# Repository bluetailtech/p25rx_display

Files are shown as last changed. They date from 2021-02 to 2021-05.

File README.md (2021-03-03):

# p25rx_display
Touch-lcd display for use with the P25RX receiver

Build Instructions (tested on a Debian system)

1) download GNU ARM Embedded Toolchain from here:
2) https://developer.arm.com/tools-and-software/open-source-software/developer-tools/gnu-toolchain/gnu-rm/downloads
3) The current firmare was compiled with version: 7-2018q2-update
4) Create a symbolic link to the compiler in the project directory:  'ln -s gcc-arm-none-eabi-7-2018-q2-update arm-toolchain'
5) Now you can compile the project from the project directory with:  'make'
6) Flip SW2 to the ON position before supplying power to the pcb. This will put the MCU into DFU programming mode.
7) Download the dfu-util software: http://dfu-util.sourceforge.net/
8) Program the device with dfu-util:   'dfu-util --device 0483:df11 -a 0 -s 0x08000000 -D build/p25rx_display_DFU.bin'
9) Return SW2 to the OFF position and cycle power.

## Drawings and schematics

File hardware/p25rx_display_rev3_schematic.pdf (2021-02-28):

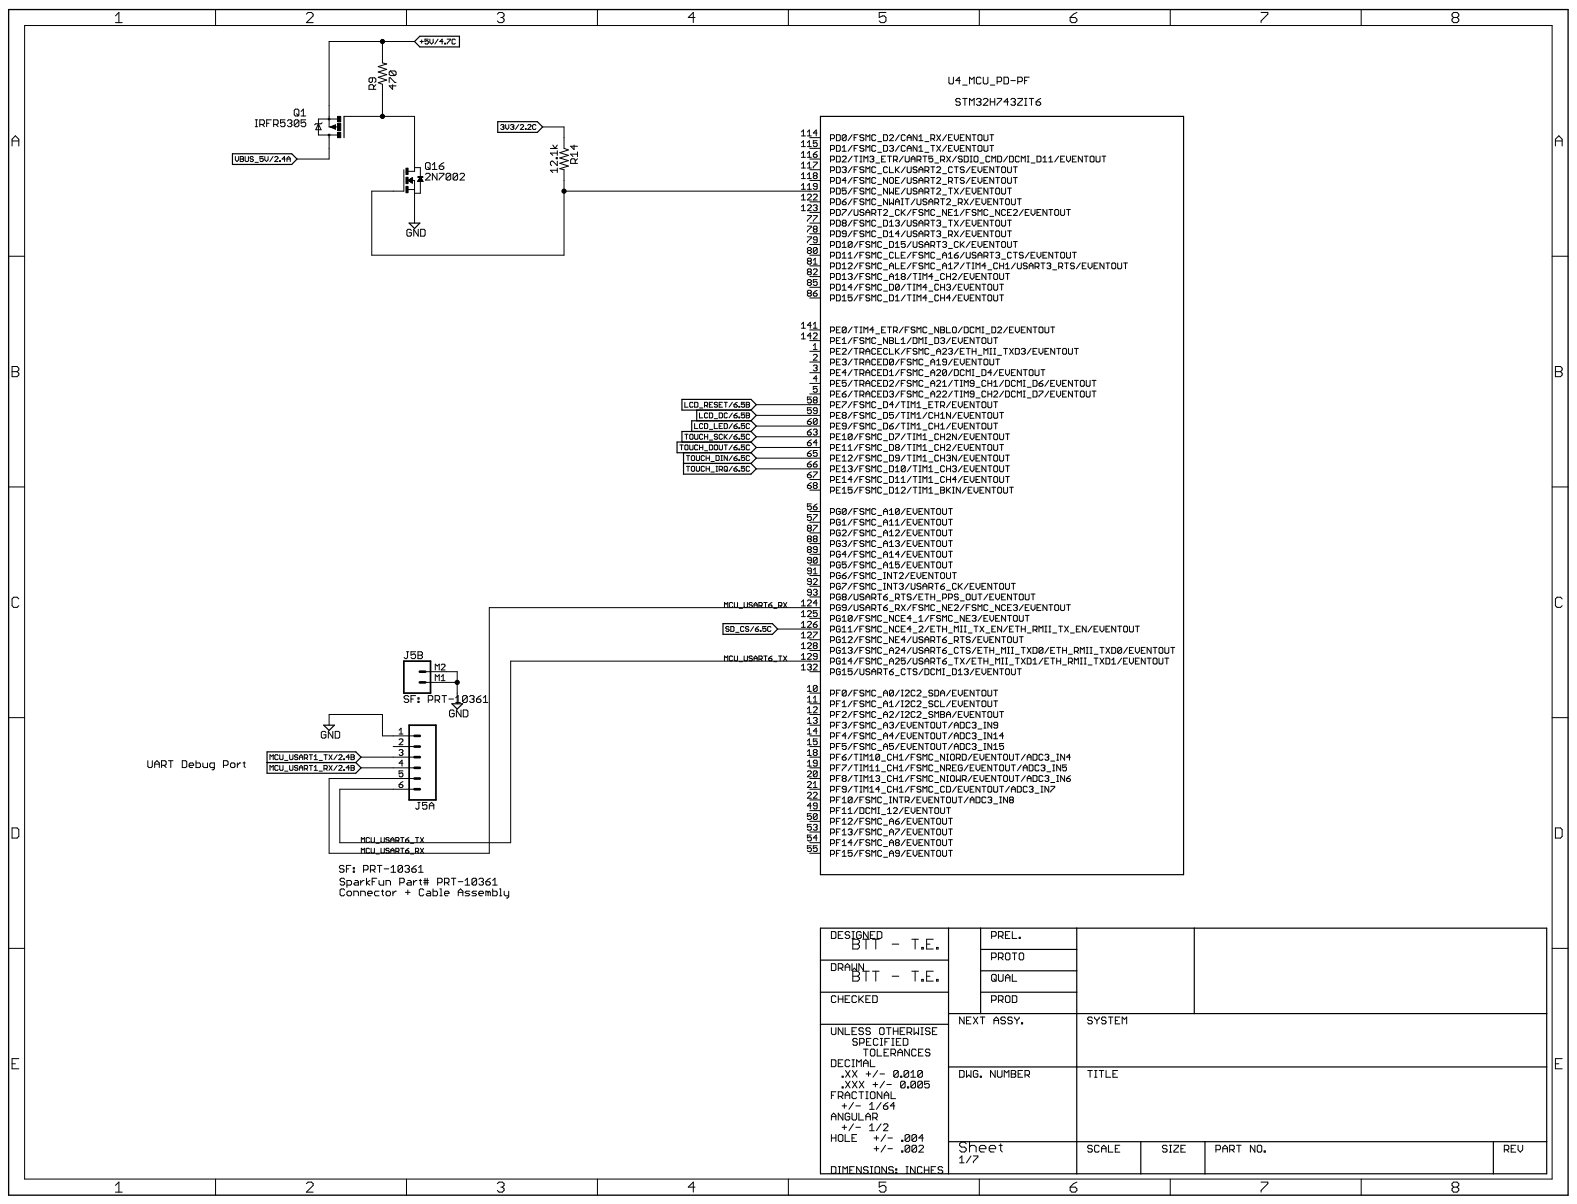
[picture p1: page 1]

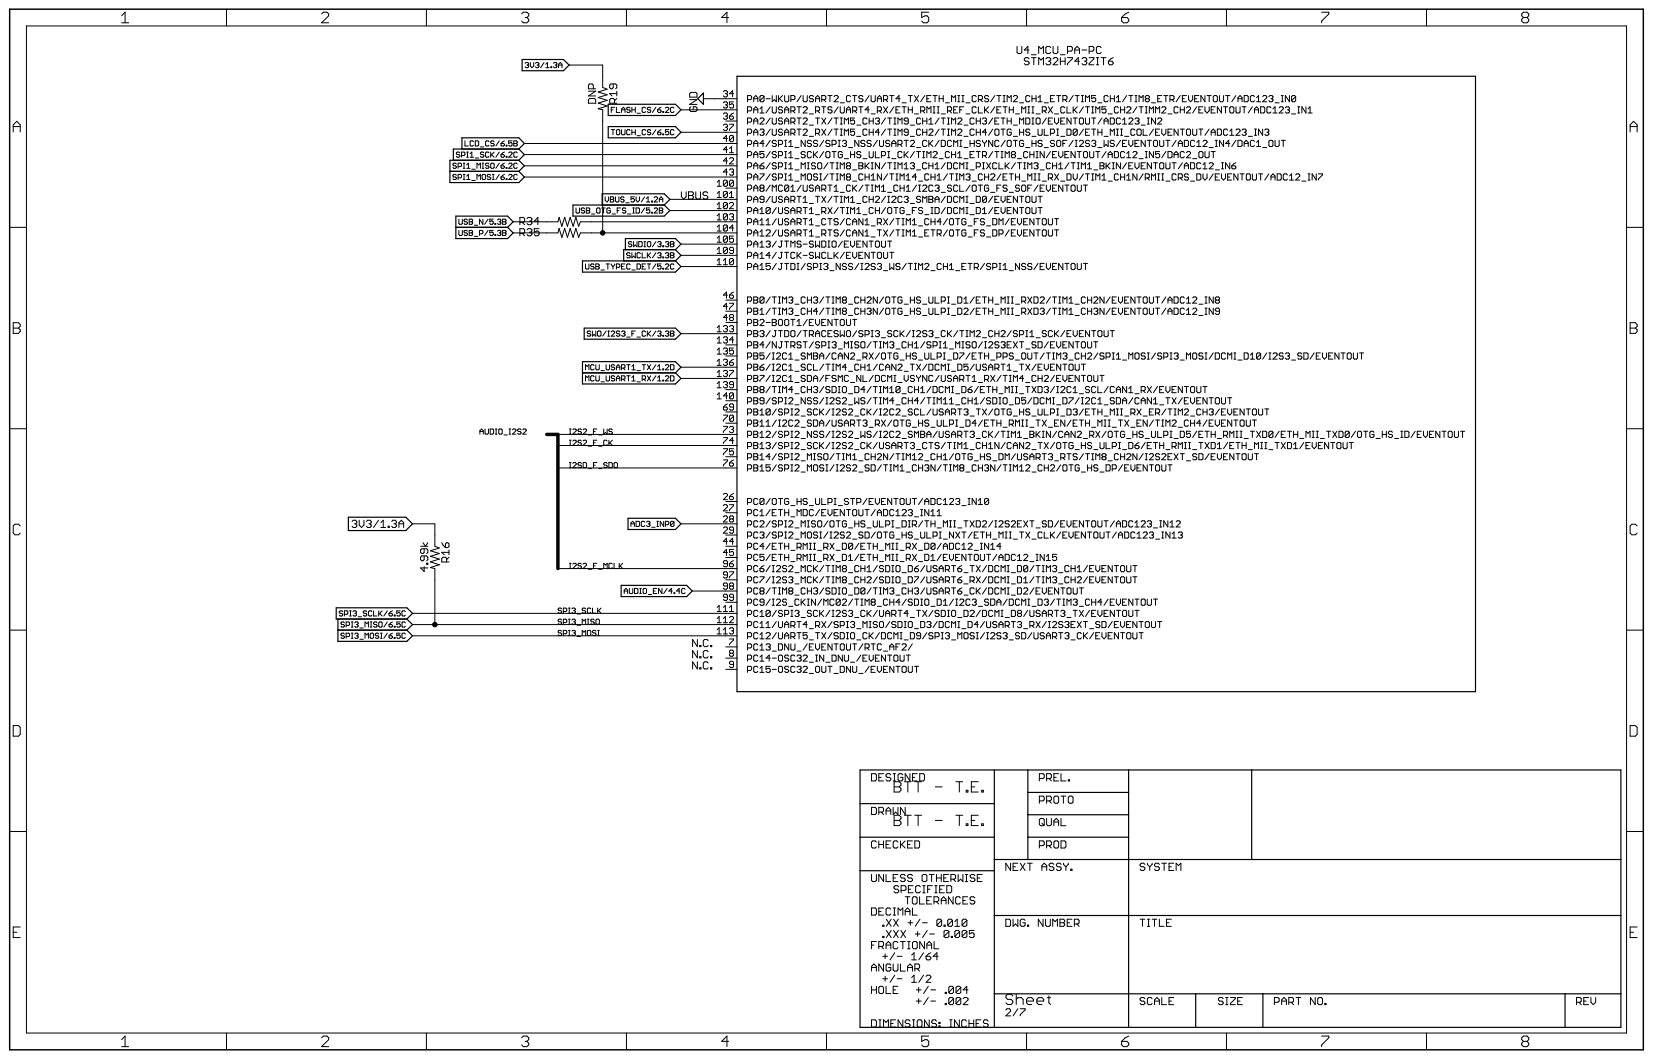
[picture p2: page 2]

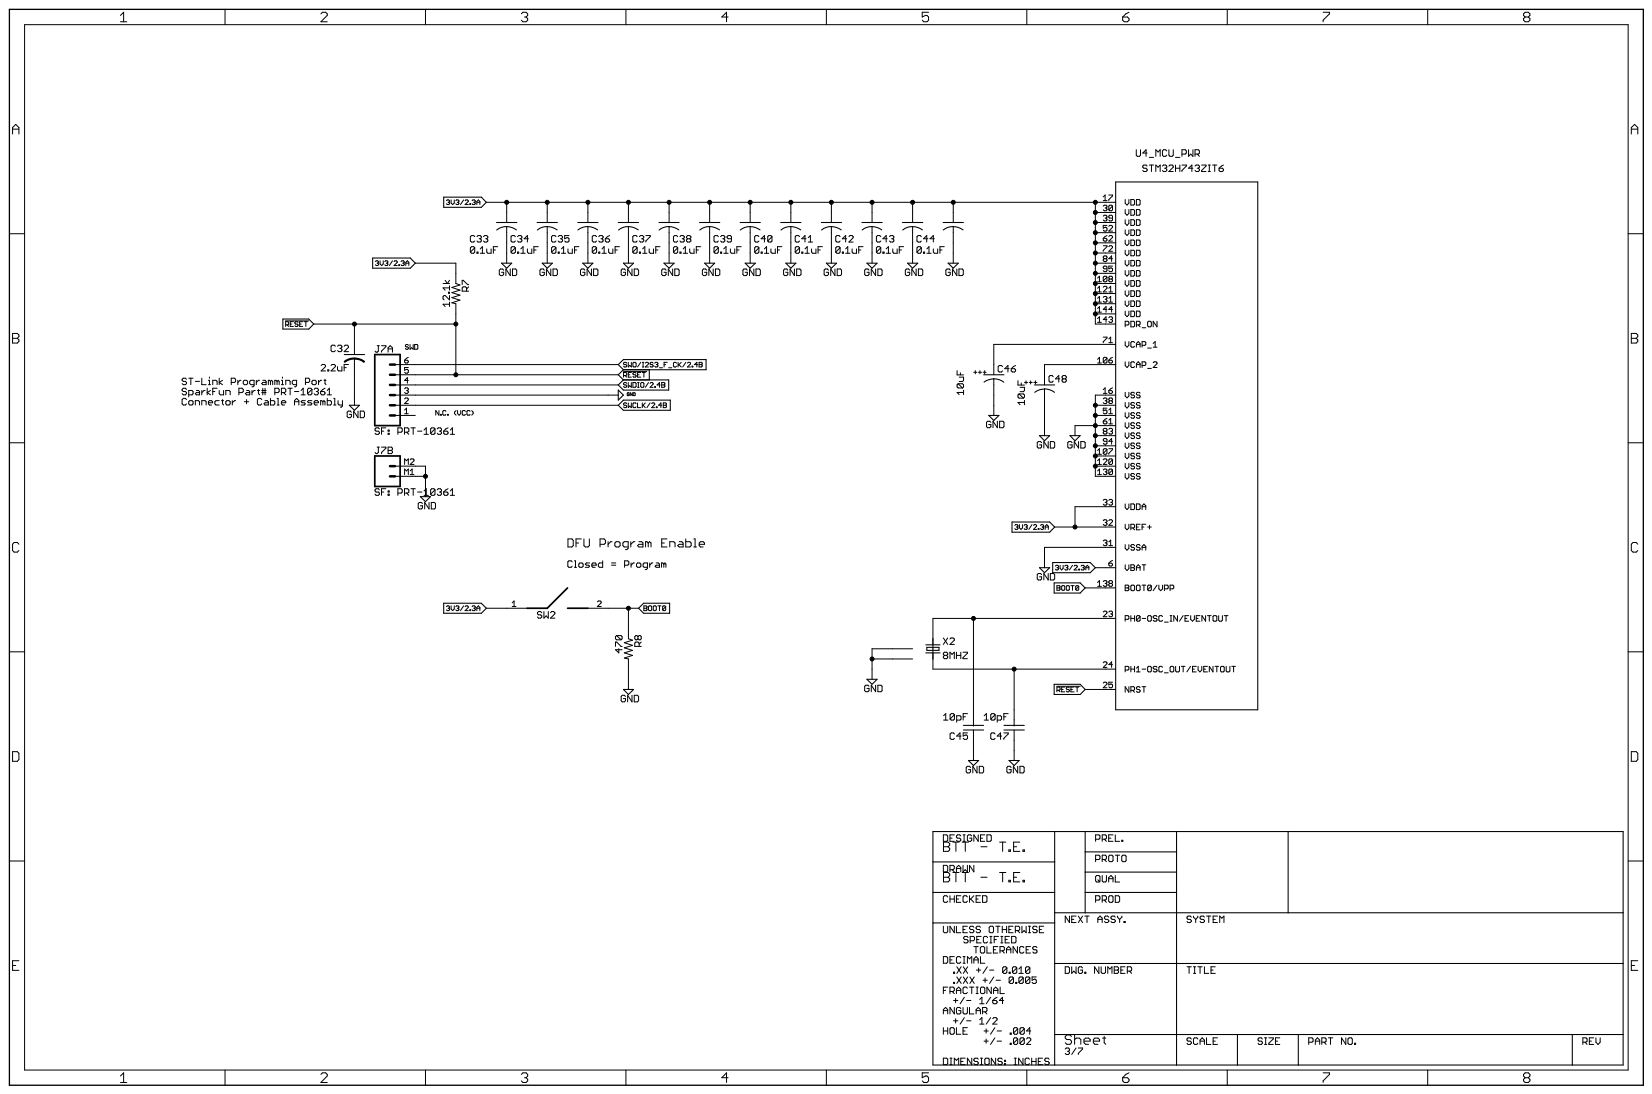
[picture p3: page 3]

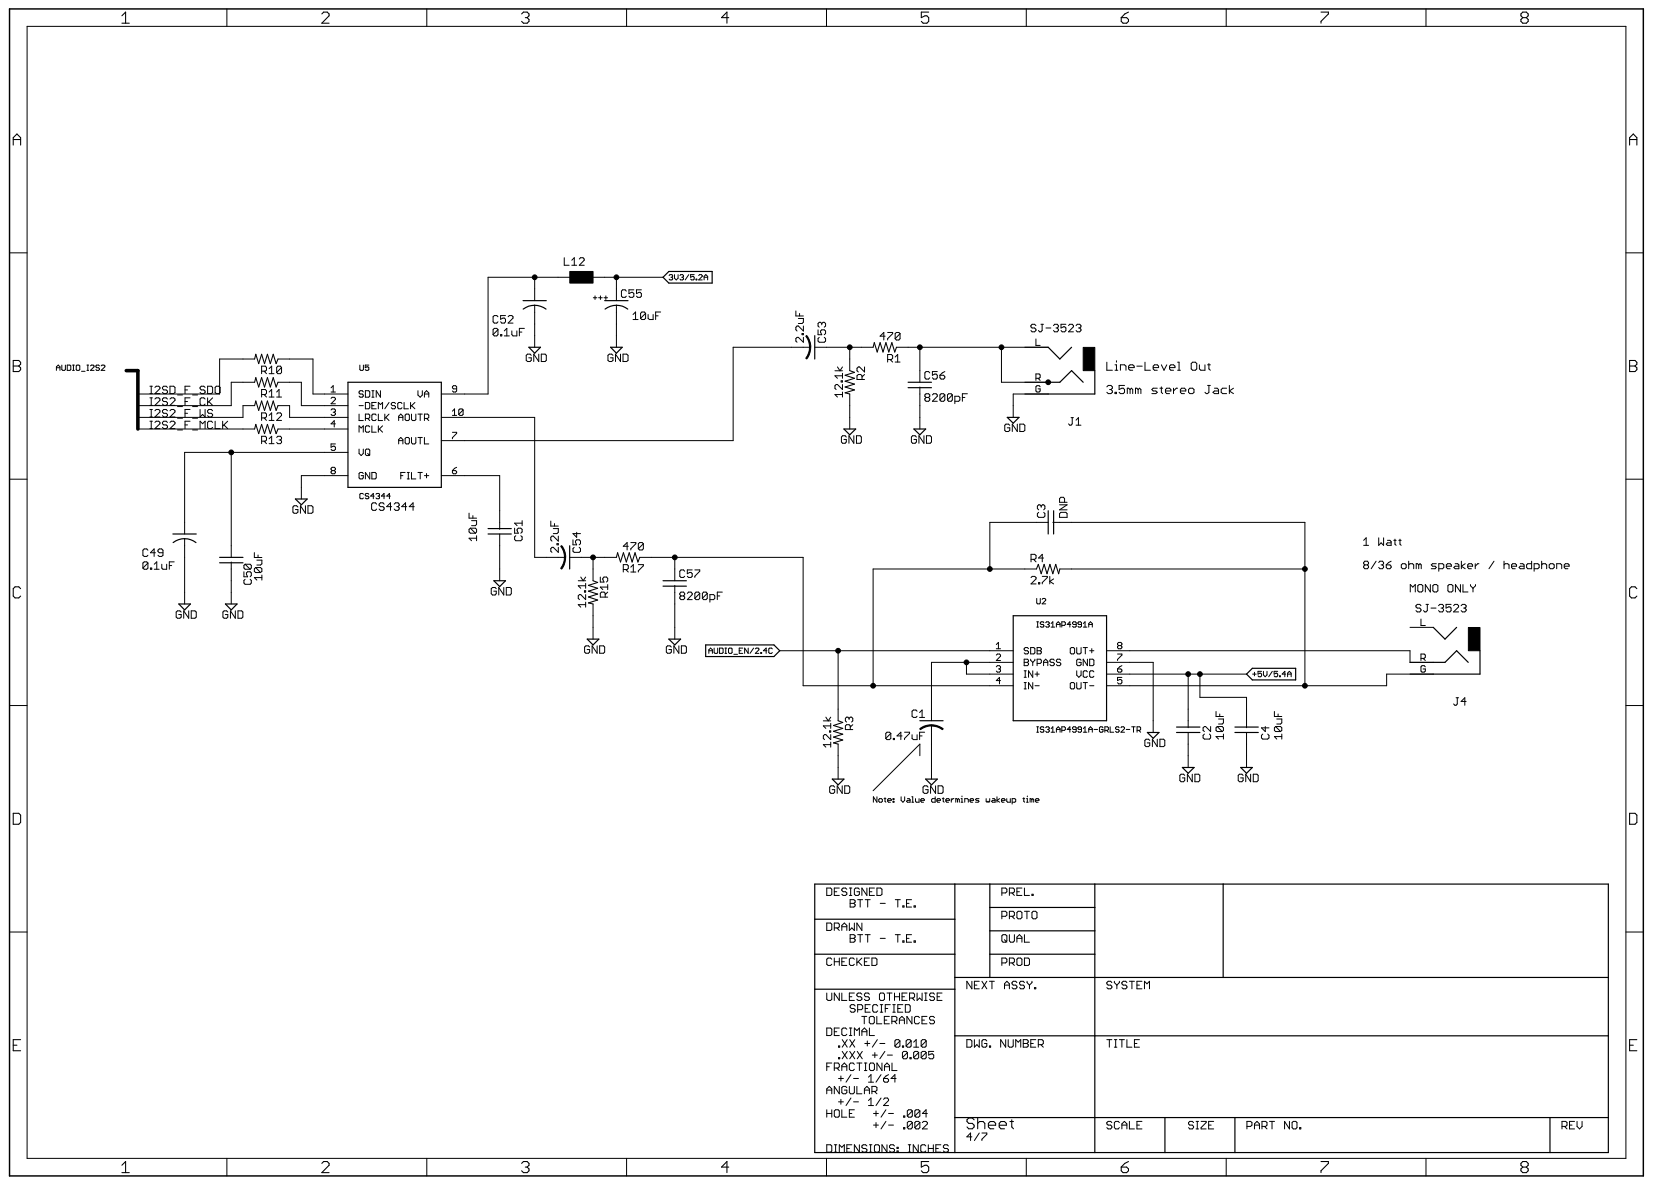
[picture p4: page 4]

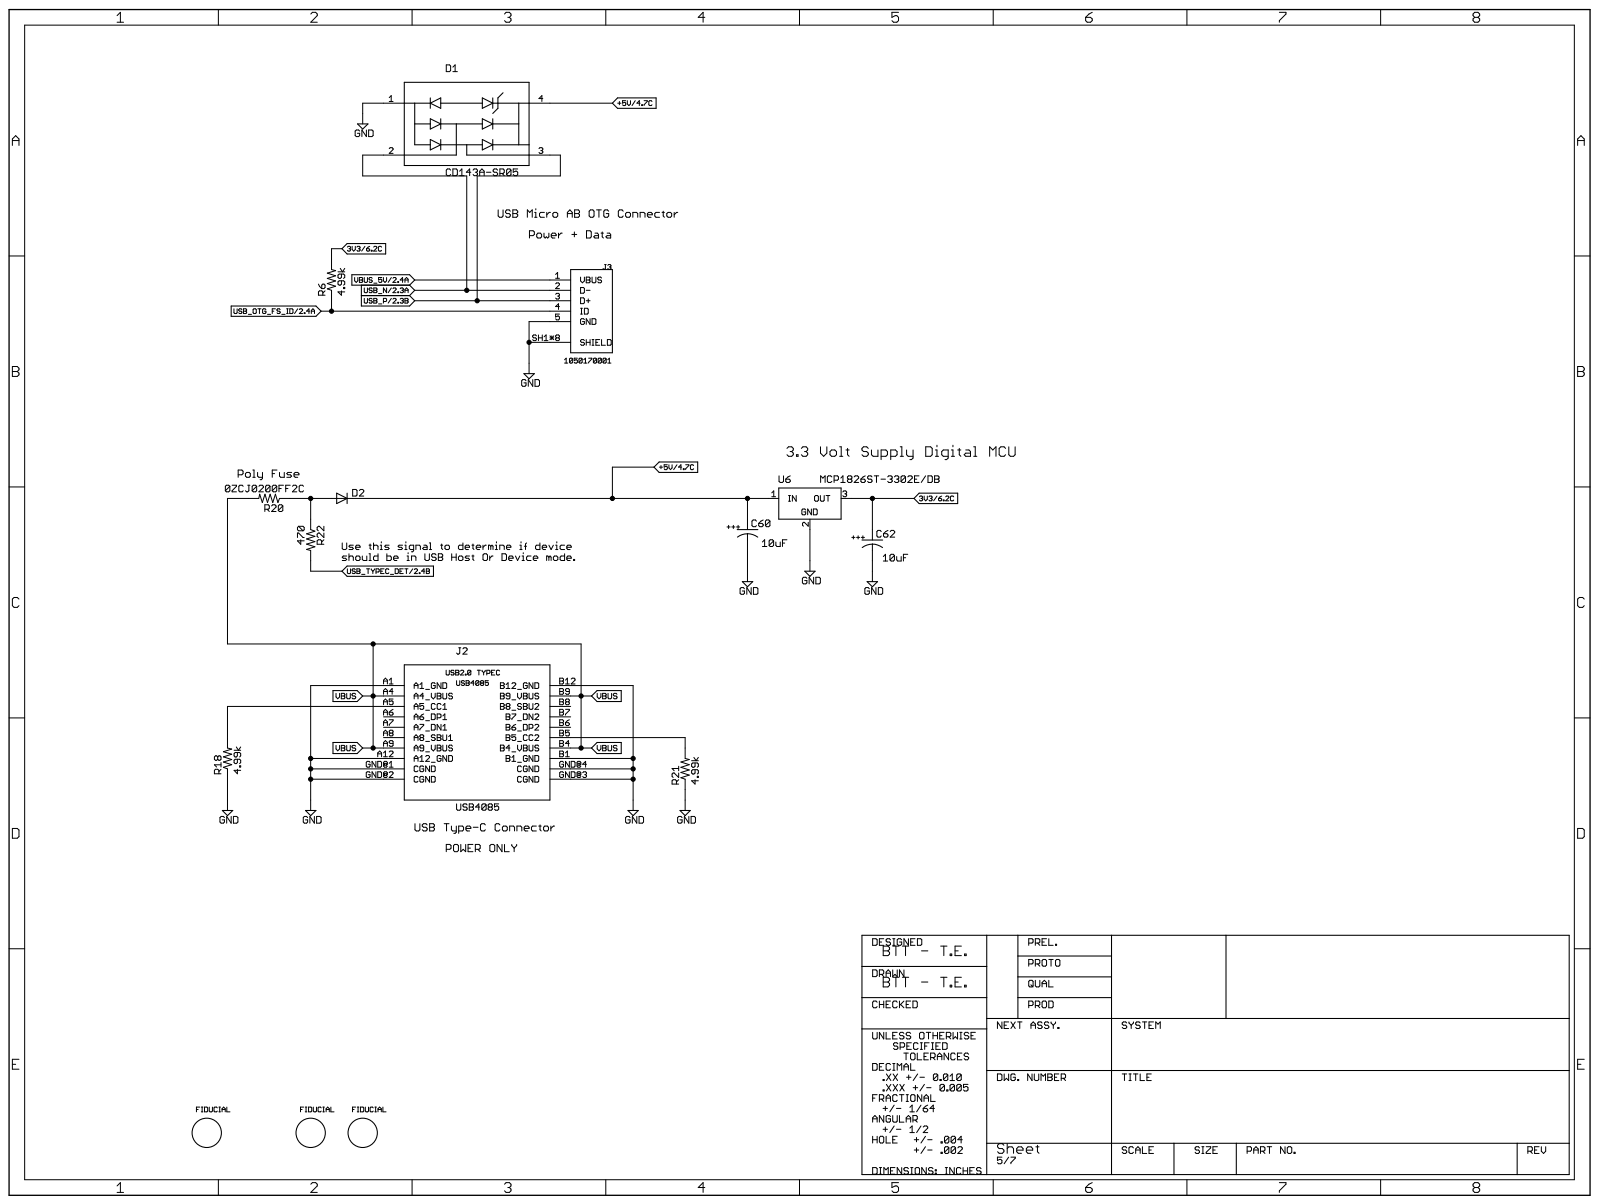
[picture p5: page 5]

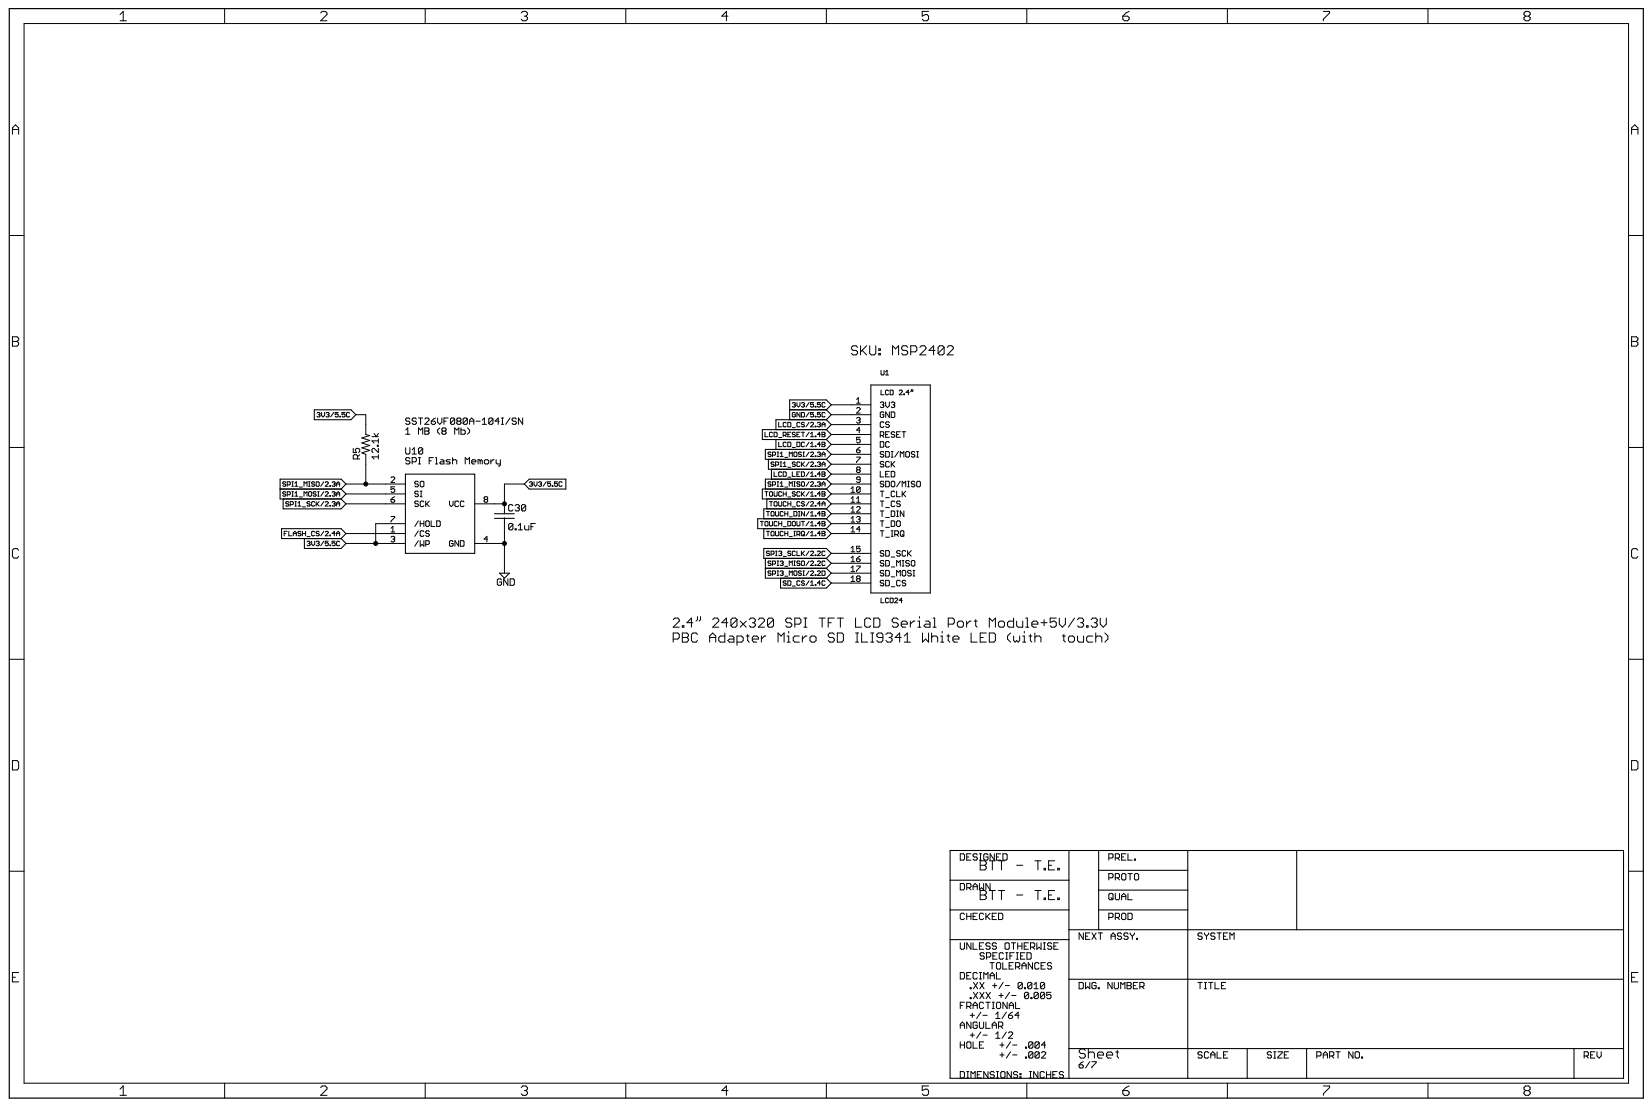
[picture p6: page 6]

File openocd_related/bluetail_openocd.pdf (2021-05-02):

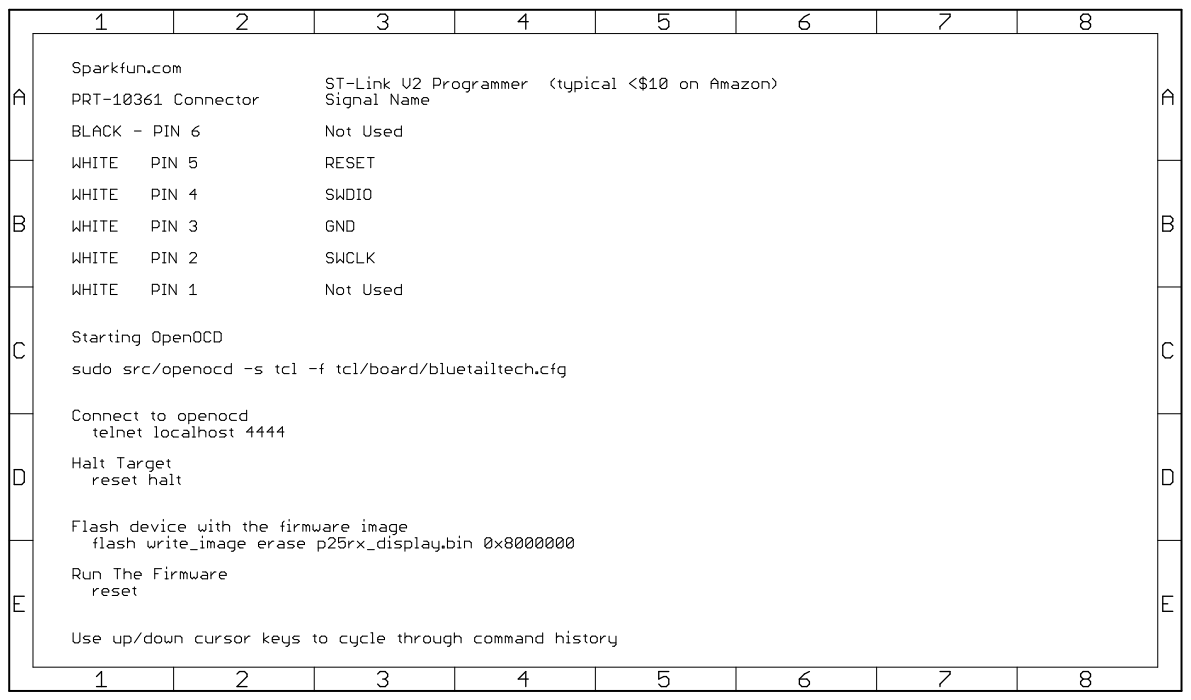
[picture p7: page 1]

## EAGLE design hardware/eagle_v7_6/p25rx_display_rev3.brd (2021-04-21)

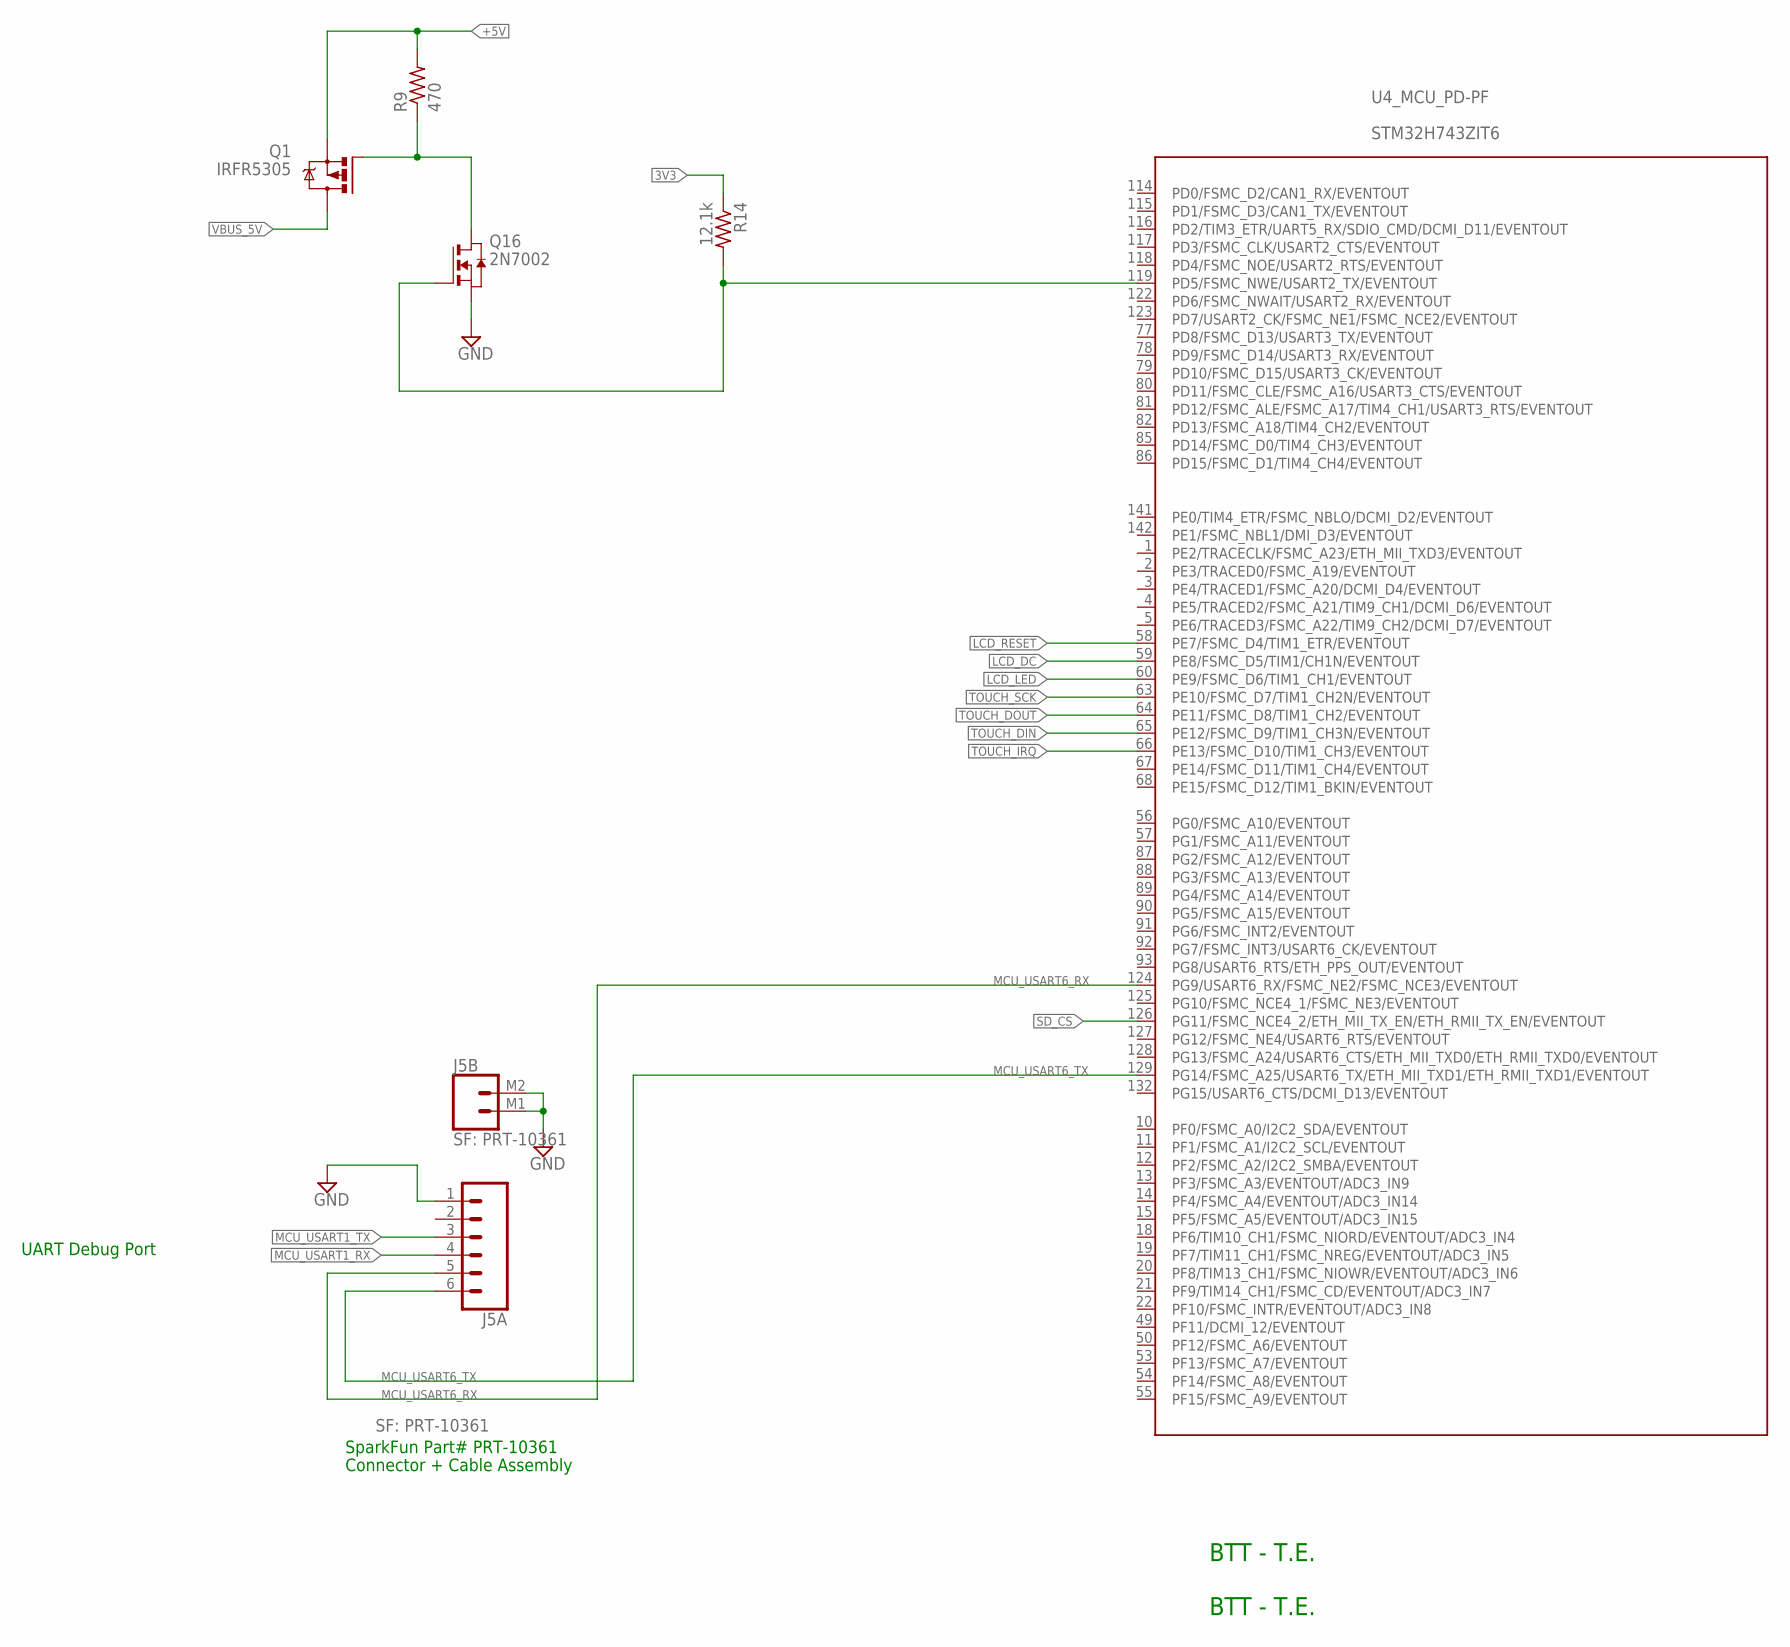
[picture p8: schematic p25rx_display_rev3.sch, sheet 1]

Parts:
J5: SF: PRT-10361; JST-6-SMD-HORI-1.0MM
Q1: IRFR5305; D-PAK_TO252AA
Q16: 2N7002; SOT23_2N7002_PACKAGE
R9: 470; R0603
R14: 12.1k; R0402
U4: STM32H743ZIT6; STM32F407_144

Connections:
3V3: R14.1; also elsewhere on the board
+5V: Q1.3 (S), R9.2; also elsewhere on the board
GND: J5.1, J5.M1 (1), J5.M2 (2), Q16.2 (S); also elsewhere on the board
LCD_DC: U4.59 (PE8/FSMC_D5/TIM1/CH1N/EVENTOUT); also elsewhere on the board
LCD_LED: U4.60 (PE9/FSMC_D6/TIM1_CH1/EVENTOUT); also elsewhere on the board
LCD_RESET: U4.58 (PE7/FSMC_D4/TIM1_ETR/EVENTOUT); also elsewhere on the board
MCU_USART1_RX: J5.4; also elsewhere on the board
MCU_USART1_TX: J5.3; also elsewhere on the board
MCU_USART6_RX: J5.5, U4.124 (PG9/USART6_RX/FSMC_NE2/FSMC_NCE3/EVENTO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)
MCU_USART6_TX: J5.6, U4.129 (PG14/FSMC_A25/USART6_TX/ETH_MII_TXD1/ET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)
unnamed: Q16.1 (G), R14.2, U4.119 (PD5/FSMC_NWE/USART2_TX/EVENTOUT)
unnamed: Q1.1 (G), Q16.3 (D), R9.1
SD_CS: U4.126 (PG11/FSMC_NCE4_2/ETH_MII_TX_EN/ETH_RMII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); also elsewhere on the board
TOUCH_DIN: U4.65 (PE12/FSMC_D9/TIM1_CH3N/EVENTOUT); also elsewhere on the board
TOUCH_DOUT: U4.64 (PE11/FSMC_D8/TIM1_CH2/EVENTOUT); also elsewhere on the board
TOUCH_IRQ: U4.66 (PE13/FSMC_D10/TIM1_CH3/EVENTOUT); also elsewhere on the board
TOUCH_SCK: U4.63 (PE10/FSMC_D7/TIM1_CH2N/EVENTOUT); also elsewhere on the board
VBUS_5V: Q1.4 (D); also elsewhere on the board

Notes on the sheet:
BTT - T.E.
UART Debug Port
SparkFun Part# PRT-10361
Connector + Cable Assembly

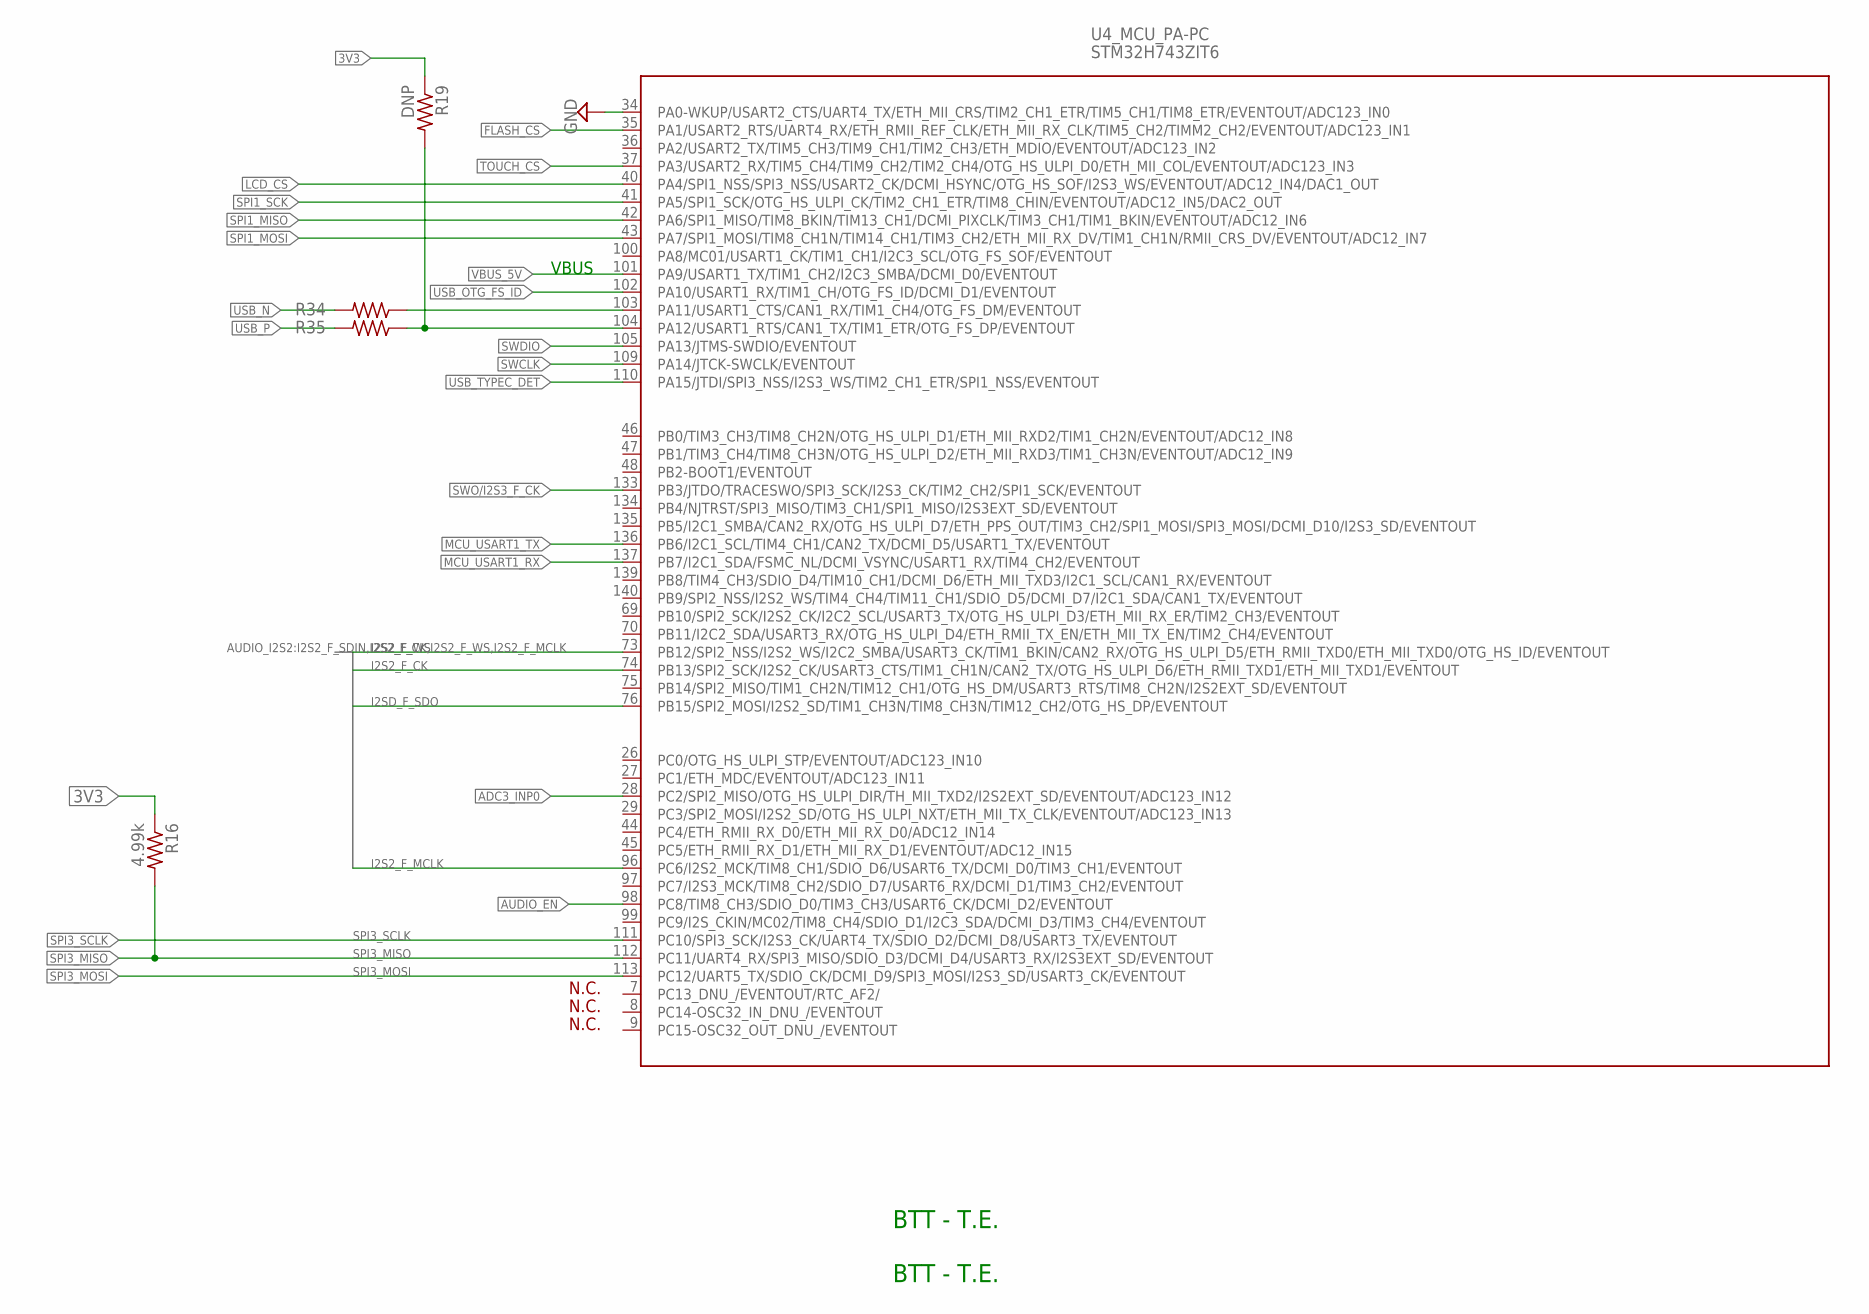
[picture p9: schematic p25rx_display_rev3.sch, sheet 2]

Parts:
R16: 4.99k; R0402
R19: DNP; R0603
R34, R35: 470; R0402
U4: STM32H743ZIT6; STM32F407_144

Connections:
3V3: R16.1, R19.1; also elsewhere on the board
ADC3_INP0: U4.28 (PC2/SPI2_MISO/OTG_HS_ULPI_DIR/TH_MII_TX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)
AUDIO_EN: U4.98 (PC8/TIM8_CH3/SDIO_D0/TIM3_CH3/USART6_CK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); also elsewhere on the board
FLASH_CS: U4.35 (PA1/USART2_RTS/UART4_RX/ETH_RMII_REF_CL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); also elsewhere on the board
GND: U4.34 (PA0-WKUP/USART2_CTS/UART4_TX/ETH_MII_CR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); also elsewhere on the board
I2S2_F_CK: U4.74 (PB13/SPI2_SCK/I2S2_CK/USART3_CTS/TIM1_C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); also elsewhere on the board
I2S2_F_MCLK: U4.96 (PC6/I2S2_MCK/TIM8_CH1/SDIO_D6/USART6_TX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); also elsewhere on the board
I2S2_F_WS: U4.73 (PB12/SPI2_NSS/I2S2_WS/I2C2_SMBA/USART3_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); also elsewhere on the board
I2SD_F_SDO: U4.76 (PB15/SPI2_MOSI/I2S2_SD/TIM1_CH3N/TIM8_C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); also elsewhere on the board
LCD_CS: U4.40 (PA4/SPI1_NSS/SPI3_NSS/USART2_CK/DCMI_HS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); also elsewhere on the board
MCU_USART1_RX: U4.137 (PB7/I2C1_SDA/FSMC_NL/DCMI_VSYNC/USART1_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); also elsewhere on the board
MCU_USART1_TX: U4.136 (PB6/I2C1_SCL/TIM4_CH1/CAN2_TX/DCMI_D5/U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); also elsewhere on the board
SPI1_MISO: U4.42 (PA6/SPI1_MISO/TIM8_BKIN/TIM13_CH1/DCMI_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); also elsewhere on the board
SPI1_MOSI: U4.43 (PA7/SPI1_MOSI/TIM8_CH1N/TIM14_CH1/TIM3_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); also elsewhere on the board
SPI1_SCK: U4.41 (PA5/SPI1_SCK/OTG_HS_ULPI_CK/TIM2_CH1_ET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); also elsewhere on the board
SPI3_MISO: R16.2, U4.112 (PC11/UART4_RX/SPI3_MISO/SDIO_D3/DCMI_D4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); also elsewhere on the board
SPI3_MOSI: U4.113 (PC12/UART5_TX/SDIO_CK/DCMI_D9/SPI3_MOSI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); also elsewhere on the board
SPI3_SCLK: U4.111 (PC10/SPI3_SCK/I2S3_CK/UART4_TX/SDIO_D2/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); also elsewhere on the board
SWCLK: U4.109 (PA14/JTCK-SWCLK/EVENTOUT); also elsewhere on the board
SWDIO: U4.105 (PA13/JTMS-SWDIO/EVENTOUT); also elsewhere on the board
SWO/I2S3_F_CK: U4.133 (PB3/JTDO/TRACESWO/SPI3_SCK/I2S3_CK/TIM2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); also elsewhere on the board
TOUCH_CS: U4.37 (PA3/USART2_RX/TIM5_CH4/TIM9_CH2/TIM2_CH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); also elsewhere on the board
USB_MCU_N: R34.1, U4.103 (PA11/USART1_CTS/CAN1_RX/TIM1_CH4/OTG_FS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)
USB_MCU_P: R19.2, R35.1, U4.104 (PA12/USART1_RTS/CAN1_TX/TIM1_ETR/OTG_FS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)
USB_N: R34.2; also elsewhere on the board
USB_OTG_FS_ID: U4.102 (PA10/USART1_RX/TIM1_CH/OTG_FS_ID/DCMI_D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); also elsewhere on the board
USB_P: R35.2; also elsewhere on the board
USB_TYPEC_DET: U4.110 (PA15/JTDI/SPI3_NSS/I2S3_WS/TIM2_CH1_ETR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); also elsewhere on the board
VBUS_5V: U4.101 (PA9/USART1_TX/TIM1_CH2/I2C3_SMBA/DCMI_D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); also elsewhere on the board

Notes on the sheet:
BTT - T.E.
VBUS

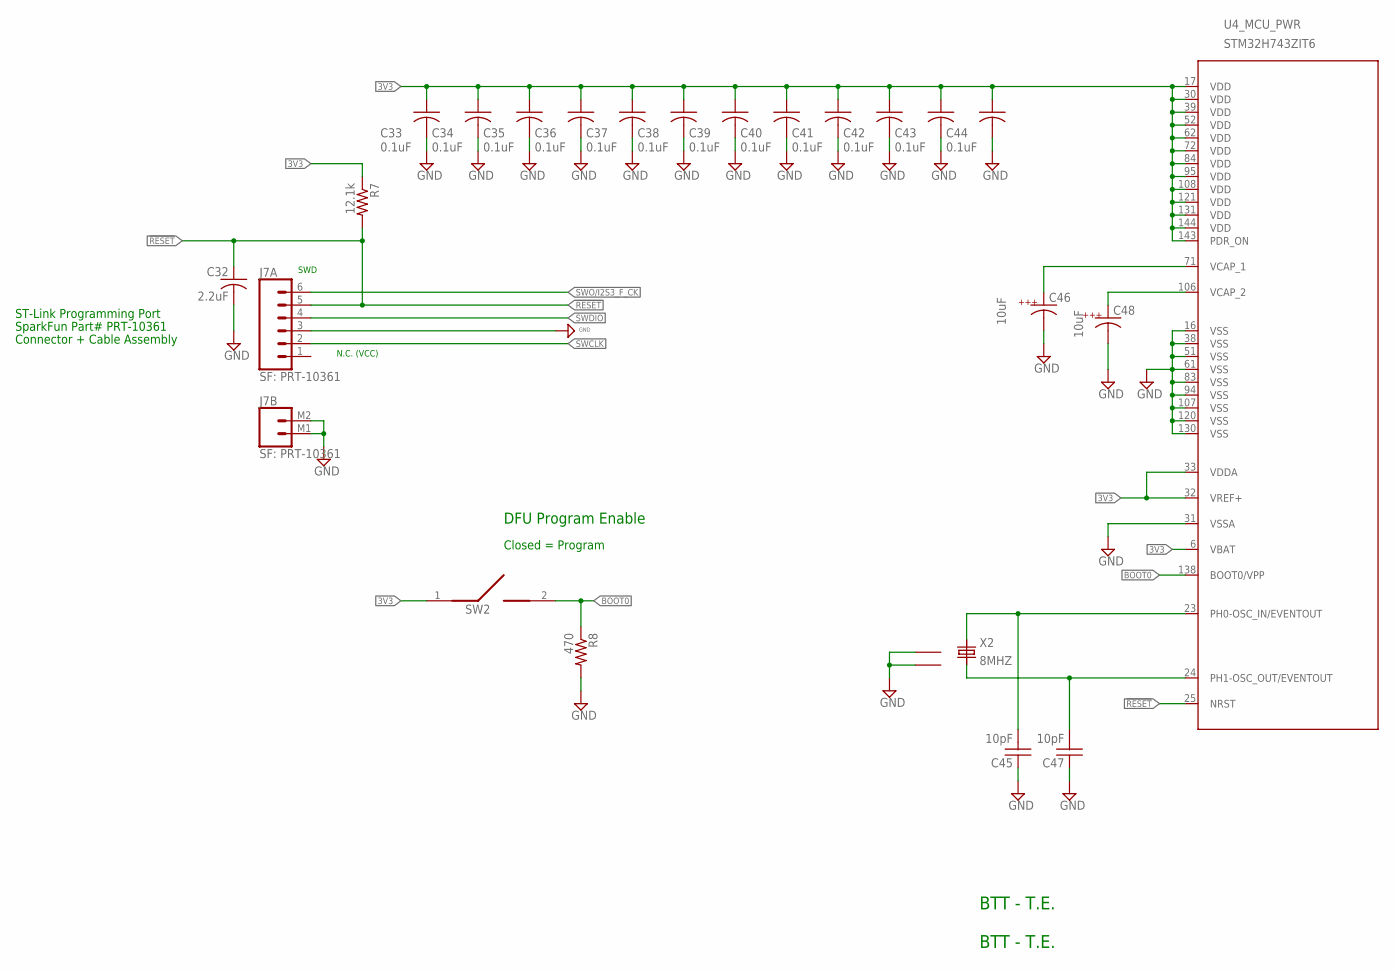
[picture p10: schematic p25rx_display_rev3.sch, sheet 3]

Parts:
C32: 2.2uF; C0805
C33, C34, C35, C36, C37, C38, C39, C40, C41, C42, C43, C44: 0.1uF; 0402
C45, C47: 10pF; C0603
C46, C48: 10uF; 1210K
J7: SF: PRT-10361; JST-6-SMD-HORI-1.0MM
R7: 12.1k; R0603
R8: 470; R0402
SW2: CHS-01TA; CHS1BIT
U4: STM32H743ZIT6; STM32F407_144
X2: 8MHZ; ECS-250-20-30B-DU_CRYSTAL

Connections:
3V3: C33.1 (A), C34.1 (A), C35.1 (A), C36.1 (A), C37.1 (A), C38.1 (A), C39.1 (A), C40.1 (A), C41.1 (A), C42.1 (A), C43.1 (A), C44.1 (A), R7.1, SW2.1, U4.6 (VBAT), U4.17 (VDD), U4.30 (VDD), U4.32 (VREF+), U4.33 (VDDA), U4.39 (VDD), U4.52 (VDD), U4.62 (VDD), U4.72 (VDD), U4.84 (VDD), U4.95 (VDD), U4.108 (VDD), U4.121 (VDD), U4.131 (VDD), U4.143 (PDR_ON), U4.144 (VDD); also elsewhere on the board
20MHZ_REF: C45.2, U4.23 (PH0-OSC_IN/EVENTOUT), X2.1
!RESET: C32.1, J7.5, R7.2, U4.25 (NRST)
BOOT0: R8.1, SW2.2, U4.138 (BOOT0/VPP)
GND: C32.2, C33.2 (C), C34.2 (C), C35.2 (C), C36.2 (C), C37.2 (C), C38.2 (C), C39.2 (C), C40.2 (C), C41.2 (C), C42.2 (C), C43.2 (C), C44.2 (C), C45.1, C46.C, C47.1, C48.C, J7.3, J7.M1 (1), J7.M2 (2), R8.2, U4.16 (VSS), U4.31 (VSSA), U4.38 (VSS), U4.51 (VSS), U4.61 (VSS), U4.83 (VSS), U4.94 (VSS), U4.107 (VSS), U4.120 (VSS), U4.130 (VSS), X2.GND@1 (1), X2.GND@2 (2); also elsewhere on the board
unnamed: C48.A, U4.106 (VCAP_2)
unnamed: C46.A, U4.71 (VCAP_1)
SWCLK: J7.2; also elsewhere on the board
SWDIO: J7.4; also elsewhere on the board
SWO/I2S3_F_CK: J7.6; also elsewhere on the board
X2: C47.2, U4.24 (PH1-OSC_OUT/EVENTOUT), X2.3

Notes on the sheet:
BTT - T.E.
SWD
N.C. (VCC)
DFU Program Enable
Closed = Program
ST-Link Programming Port
SparkFun Part# PRT-10361
Connector + Cable Assembly

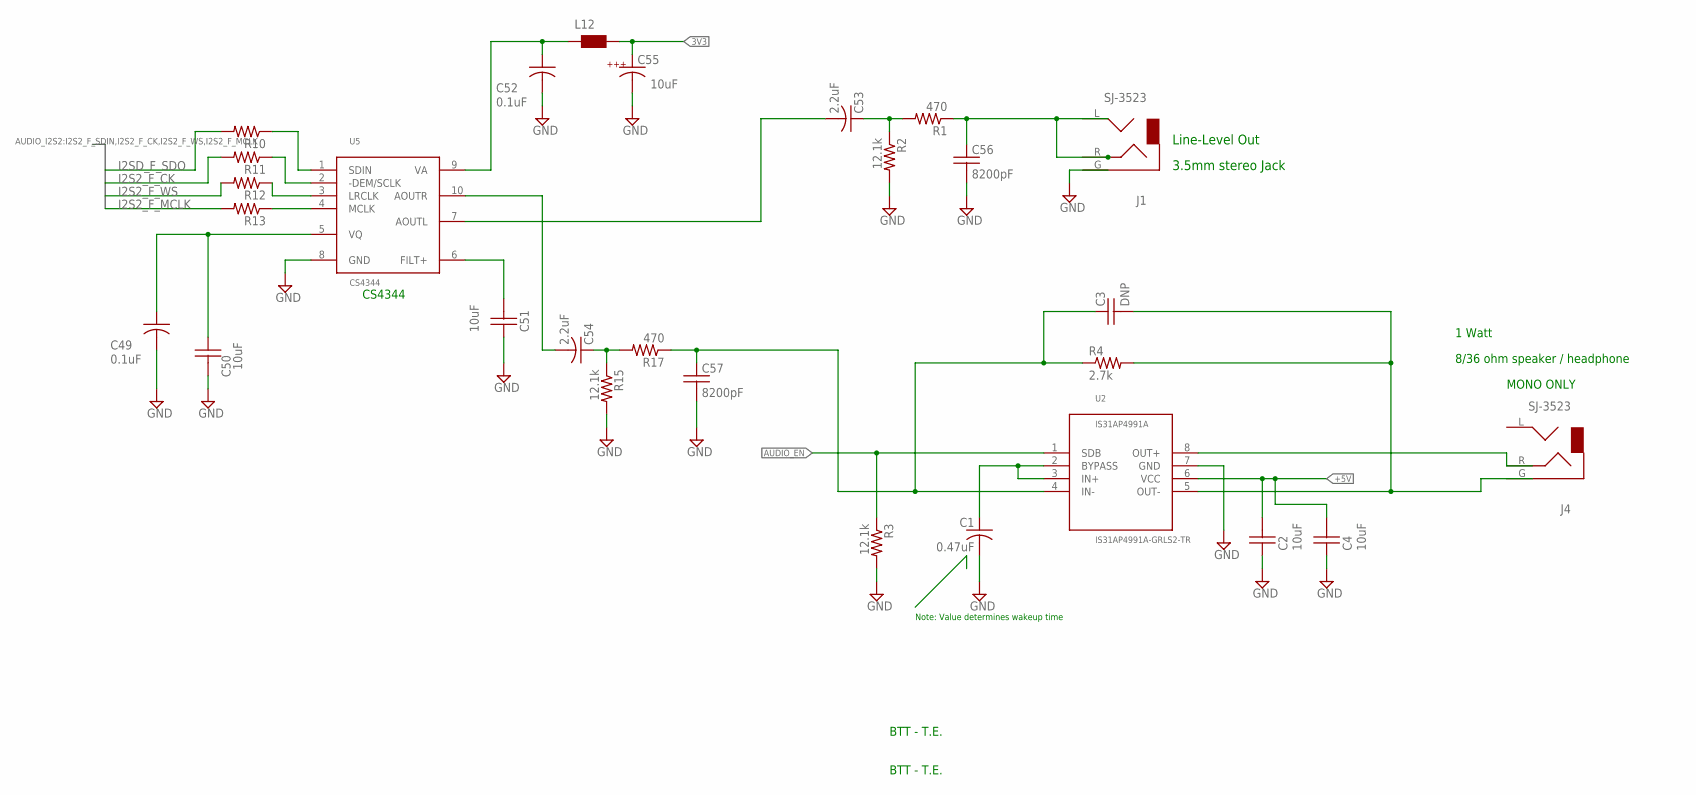
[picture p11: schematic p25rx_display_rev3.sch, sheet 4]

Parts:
C1: 0.47uF; C0805
C2, C4, C50, C51: 10uF; C0805
C3: DNP; C0603
C49, C52: 0.1uF; 0402
C53, C54: 2.2uF; C0805
C55: 10uF; 1210K
C56, C57: 8200pF; C0603
J1, J4: SJ-3523
L12: WE-CBF_0603; 0603
R1, R10, R11, R12, R13, R17: 470; R0402
R2, R3, R15: 12.1k; R0603
R4: 2.7k; R0603
U2: IS31AP4991A-GRLS2-TR; SO8
U5: CS4344; MSOP10

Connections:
3V3: C55.A, L12.2; also elsewhere on the board
+5V: C2.2, C4.2, U2.6 (VCC); also elsewhere on the board
AUDIO_EN: R3.1, U2.1 (SDB); also elsewhere on the board
AUDIO_LEFT: C56.1, J1.L, J1.R, R1.1
AUDIO_RIGHT: C3.1, C57.1, R4.1, R17.1, U2.4 (IN-)
GND: C1.2, C2.1, C4.1, C49.2 (C), C50.2, C51.1, C52.2 (C), C55.C, C56.2, C57.2, J1.G, R2.2, R3.2, R15.2, U2.7 (GND), U5.8 (GND); also elsewhere on the board
I2S2_F_CK: R11.2; also elsewhere on the board
I2S2_F_MCLK: R13.2; also elsewhere on the board
I2S2_F_WS: R12.2; also elsewhere on the board
I2SD_F_SDO: R10.2; also elsewhere on the board
unnamed: J4.R, U2.8 (OUT+)
unnamed: C1.1, U2.2 (BYPASS), U2.3 (IN+)
unnamed: C3.2, J4.G, R4.2, U2.5 (OUT-)
unnamed: C53.2, U5.7 (AOUTL)
unnamed: C54.2, U5.10 (AOUTR)
unnamed: R13.1, U5.4 (MCLK)
unnamed: R12.1, U5.3 (LRCLK)
unnamed: R11.1, U5.2 (-DEM/SCLK)
unnamed: R10.1, U5.1 (SDIN)
unnamed: C51.2, U5.6 (FILT+)
unnamed: C49.1 (A), C50.1, U5.5 (VQ)
unnamed: C53.1, R1.2, R2.1
unnamed: C54.1, R15.1, R17.2
unnamed: C52.1 (A), L12.1, U5.9 (VA)

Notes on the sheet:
BTT - T.E.
CS4344
Line-Level Out
3.5mm stereo Jack
Note: Value determines wakeup time
MONO ONLY
8/36 ohm speaker / headphone
1 Watt

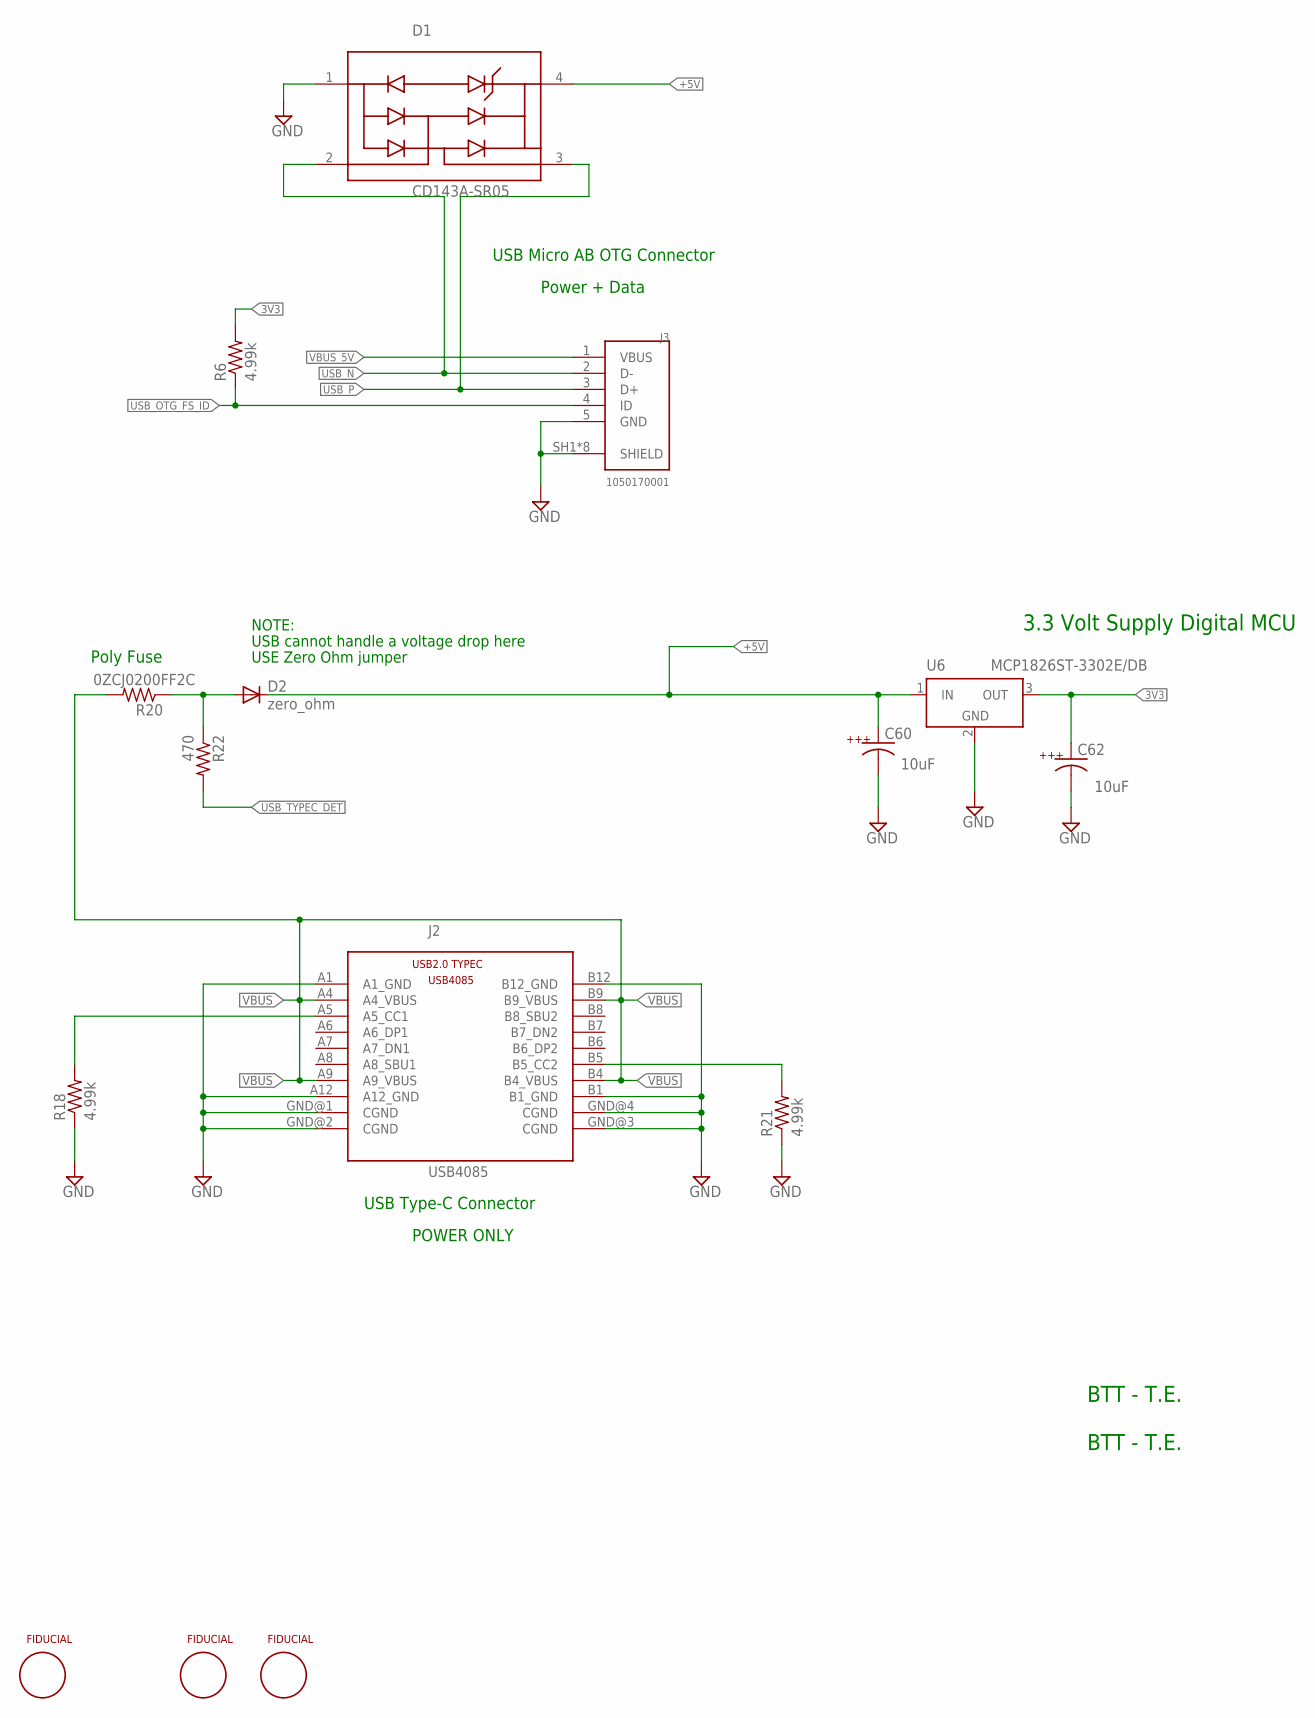
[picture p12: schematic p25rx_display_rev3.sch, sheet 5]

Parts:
C60, C62: 10uF; 1210K
D1: CD143A-SR05; SR2.8.TCT_1PRIMARY
D2: zero_ohm; SMB
FID1, FID3, FID4: FIDUCIALSMD; FIDUCIAL
J2: USB4085; GCT_PN_USB4085
J3: 1050170001; MOLEX_1050170001
R6, R18, R21: 4.99k; R0402
R20: 0ZCJ0200FF2C; R1206
R22: 470; R0402
U6: MCP1826ST-3302E/DB; SOT223

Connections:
3V3: C62.A, R6.2, U6.3 (OUT); also elsewhere on the board
+5V: C60.A, D1.4 (REF), D2.C, U6.1 (IN); also elsewhere on the board
GND: C60.C, C62.C, D1.1 (GND), J2.A1 (A1_GND), J2.A12 (A12_GND), J2.B1 (B1_GND), J2.B12 (B12_GND), J2.GND@1 (CGND), J2.GND@2 (CGND), J2.GND@3 (CGND), J2.GND@4 (CGND), J3.5 (GND), J3.SH1 (SHIELD), J3.SH2 (SHIELD), J3.SH3 (SHIELD), J3.SH4 (SHIELD), J3.SH5 (SHIELD), J3.SH6 (SHIELD), J3.SH7 (SHIELD), J3.SH8 (SHIELD), R18.1, R21.1, U6.2 (GND), U6.4 (GND); also elsewhere on the board
unnamed: D2.A, R20.1, R22.1
unnamed: J2.B5 (B5_CC2), R21.2
unnamed: J2.A5 (A5_CC1), R18.2
USB_N: D1.2 (I/O), J3.2 (D-); also elsewhere on the board
USB_OTG_FS_ID: J3.4 (ID), R6.1; also elsewhere on the board
USB_P: D1.3 (I/O), J3.3 (D+); also elsewhere on the board
USB_TYPEC_DET: R22.2; also elsewhere on the board
VBUS: J2.A4 (A4_VBUS), J2.A9 (A9_VBUS), J2.B4 (B4_VBUS), J2.B9 (B9_VBUS), R20.2
VBUS_5V: J3.1 (VBUS); also elsewhere on the board

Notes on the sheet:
BTT - T.E.
3.3 Volt Supply Digital MCU
USB Type-C Connector
POWER ONLY
Poly Fuse
USB Micro AB OTG Connector
Power + Data
USB cannot handle a voltage drop here
USE Zero Ohm jumper
NOTE:

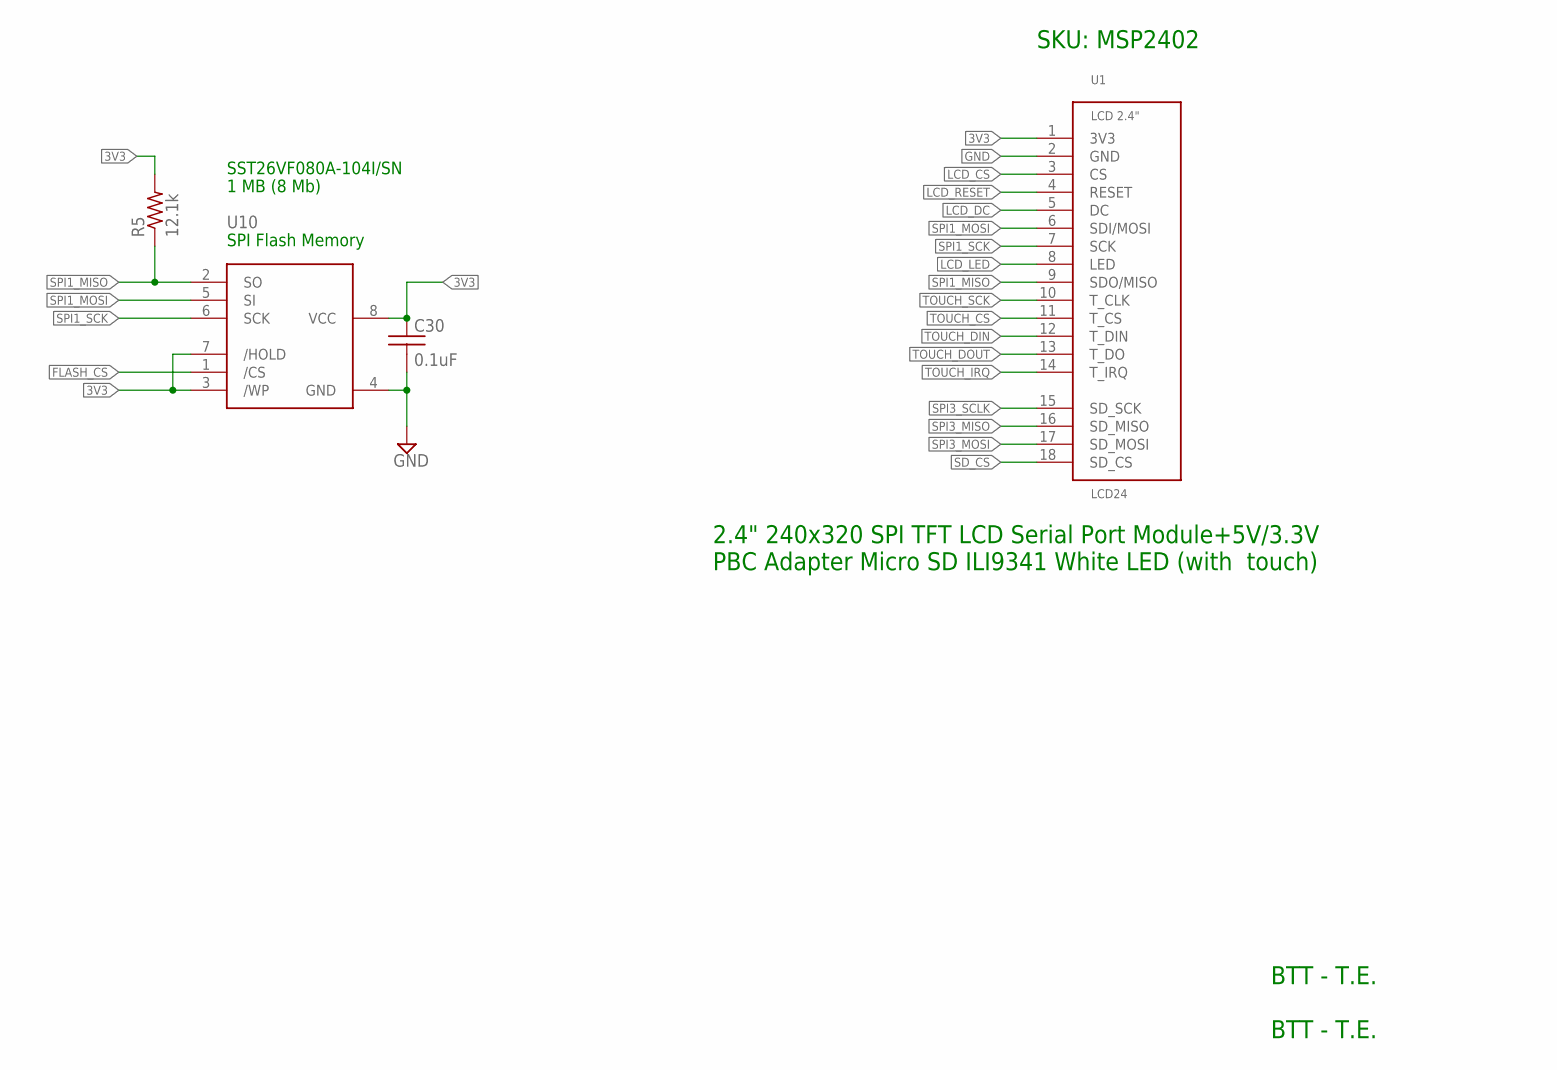
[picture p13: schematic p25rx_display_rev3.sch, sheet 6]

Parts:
C30: 0.1uF; C0402
R5: 12.1k; R0603
U1: LCD24; LCD_24
U10: AT25F512ASOIC; SO8

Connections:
3V3: C30.1, R5.2, U1.1 (3V3), U10.3 (/WP), U10.7 (/HOLD), U10.8 (VCC); also elsewhere on the board
FLASH_CS: U10.1 (/CS); also elsewhere on the board
GND: C30.2, U1.2 (GND), U10.4 (GND); also elsewhere on the board
LCD_CS: U1.3 (CS); also elsewhere on the board
LCD_DC: U1.5 (DC); also elsewhere on the board
LCD_LED: U1.8 (LED); also elsewhere on the board
LCD_RESET: U1.4 (RESET); also elsewhere on the board
SD_CS: U1.18 (SD_CS); also elsewhere on the board
SPI1_MISO: R5.1, U1.9 (SDO/MISO), U10.2 (SO); also elsewhere on the board
SPI1_MOSI: U1.6 (SDI/MOSI), U10.5 (SI); also elsewhere on the board
SPI1_SCK: U1.7 (SCK), U10.6 (SCK); also elsewhere on the board
SPI3_MISO: U1.16 (SD_MISO); also elsewhere on the board
SPI3_MOSI: U1.17 (SD_MOSI); also elsewhere on the board
SPI3_SCLK: U1.15 (SD_SCK); also elsewhere on the board
TOUCH_CS: U1.11 (T_CS); also elsewhere on the board
TOUCH_DIN: U1.12 (T_DIN); also elsewhere on the board
TOUCH_DOUT: U1.13 (T_DO); also elsewhere on the board
TOUCH_IRQ: U1.14 (T_IRQ); also elsewhere on the board
TOUCH_SCK: U1.10 (T_CLK); also elsewhere on the board

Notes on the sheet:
BTT - T.E.
SPI Flash Memory
SKU: MSP2402
2.4" 240x320 SPI TFT LCD Serial Port Module+5V/3.3V PBC Adapter Micro SD ILI9341 White LED (with touch)
SST26VF080A-104I/SN
1 MB (8 Mb)

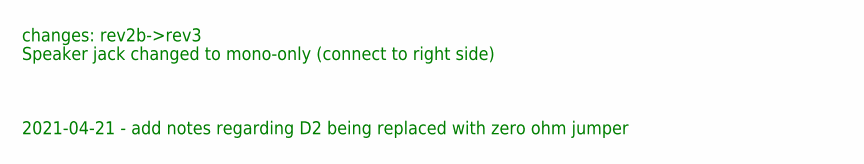
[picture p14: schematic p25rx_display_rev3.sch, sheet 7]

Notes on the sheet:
changes: rev2b->rev3
Speaker jack changed to mono-only (connect to right side)
2021-04-21 - add notes regarding D2 being replaced with zero ohm jumper

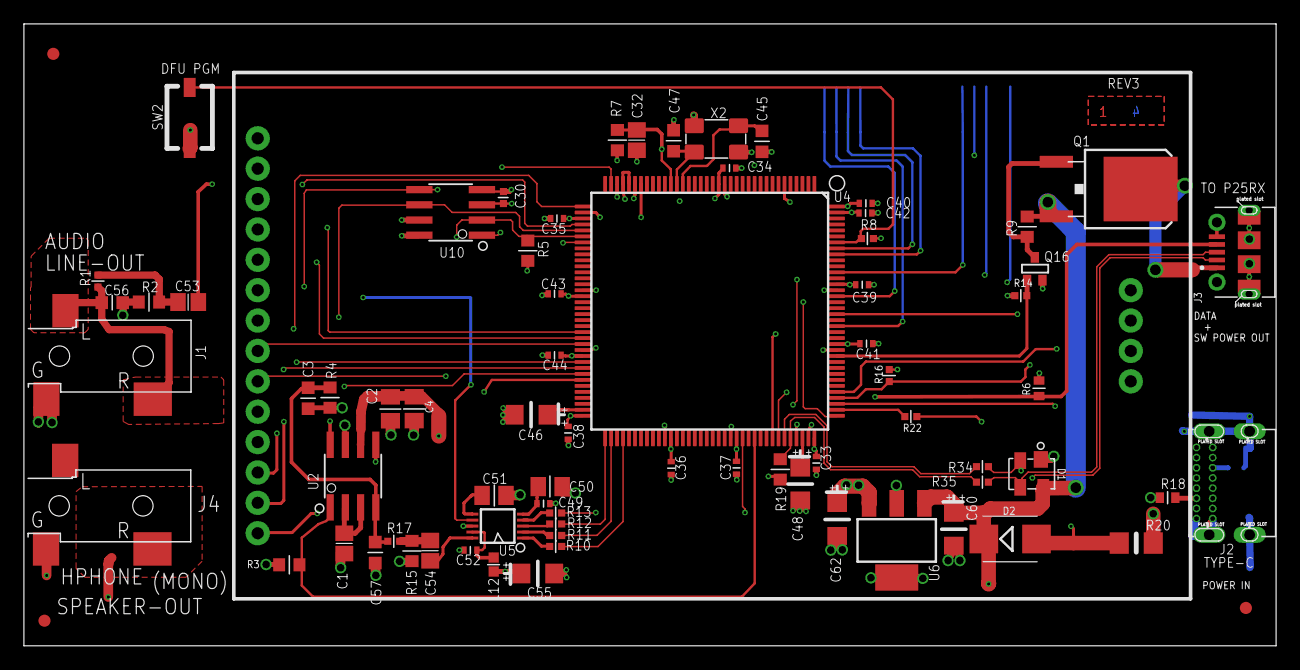
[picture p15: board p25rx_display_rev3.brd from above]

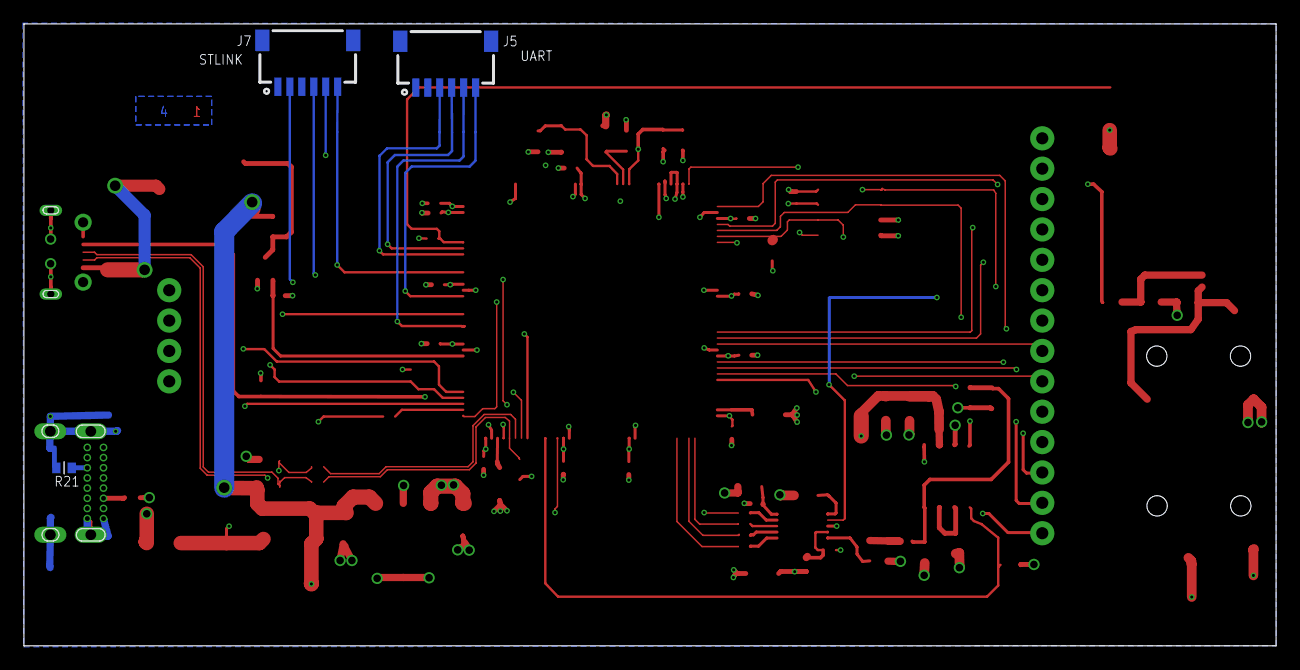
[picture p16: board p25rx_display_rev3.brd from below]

Board: 4 copper layers, 104.7 x 52.0 mm, 79 parts (3 on the bottom side), 67 nets.

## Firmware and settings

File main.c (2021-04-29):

//MIT License
//
//Copyright (c) 2020 tvelliott
//
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
#include <complex.h>
#include <math.h>

#include "main.h"
#include "stm32h7xx_hal.h"

#define ARM_MATH_CM7 1
#include "arm_common_tables.h"
#include "arm_math.h"

#include "lcd.h"
#include "lcd_buttons.h"
#include "fonts.h"

#include "usb_main_inc.h"
#include "usbh_core.h"
#include "usbh_cdc.h"

I2S_HandleTypeDef hi2s2;
DMA_HandleTypeDef hdma_spi2_tx;
void MX_I2S2_Init( void );
ALIGN_32BYTES( volatile uint16_t   audio_tx[256] __attribute__( ( section( ".AudioSection" ) ) ) ); //I2S2 audio buffer
volatile uint32_t out_s = 0;
volatile uint32_t out_e = 0;
volatile uint32_t is_playing;
volatile int audio_started;
volatile short out_buffer[AUDIO_OUT_BUFFER_SIZE];
static void MX_DMA_Init( void );
volatile uint16_t rand16;
static volatile float angle1;
static volatile float angle2;
static volatile int audio_dir;
volatile int usb_restart_count;
volatile int do_usb_start;
extern uint8_t volatile CDC_RX_Buffer[RX_BUFF_SIZE];


USBH_HandleTypeDef hUSBHost;
CDC_ApplicationTypeDef Appli_state = APPLICATION_IDLE;
static void USBH_UserProcess( USBH_HandleTypeDef *phost, uint8_t id );
void GetDefaultConfiguration( void );

static void USBH_UserProcess( USBH_HandleTypeDef *phost, uint8_t id )
{
  switch( id ) {
  case HOST_USER_SELECT_CONFIGURATION:
    break;

  case HOST_USER_DISCONNECTION:
    Appli_state = APPLICATION_DISCONNECT;

    break;

  case HOST_USER_CLASS_ACTIVE:
    GetDefaultConfiguration();
    Appli_state = APPLICATION_READY;
    break;

  case HOST_USER_CONNECTION:
    Appli_state = APPLICATION_START;
    break;

  default:
    break;
  }
}


UART_HandleTypeDef huart6;

int _mem_free( void );
void lcd_tick( void );

static int draw_mod;
static uint32_t ms_tick_time;

#define IN_BUFFER_N 32

int64_t __errno;

void SystemClock_Config( void );
static void MX_GPIO_Init( void );
static void MX_USART6_UART_Init( void );
static void MX_CRC_Init( void );

static void MPU_Config( void );
static uint32_t current_time;
static uint32_t led_time;
static uint32_t audio_test;
static uint8_t led_state;
static uint8_t audio_state;
static uint32_t clk_mhz;

static uint32_t lcd_tick_time;


//audio agc related
#define AUD_AGC_LEN 64
static volatile float audio_max[AUD_AGC_LEN];

static volatile float tmp_buffer_f[1024];
static volatile int audio_max_idx;
static volatile float aout_gain = 0.25f;
static volatile float aout_abs;
static volatile float aud_agc_max;
static volatile float gainfactor;
static volatile float gaindelta;
static volatile float maxbuf;

static int silent_cnt;
volatile int start_rx_cnt;
static volatile float volume = 0.25f;


/////////////////////////////////////////////////////////////////////////////////////
/////////////////////////////////////////////////////////////////////////////////////
int main( void )
{
  MPU_Config();

  SCB_EnableICache();
  //SCB_DisableICache();

  SCB_EnableDCache();
  //SCB_DisableDCache();

  HAL_Init();

  SystemClock_Config();

  MX_GPIO_Init();
  MX_USART6_UART_Init();

  printf( "\r\n\r\nInstruction Cache Enabled" );
  printf( "\r\nData Cache Enabled" );
  printf( "\r\nHAL Initialized" );

  //HAL_Delay(1000);

  clk_mhz = SystemCoreClock / 1e6;
  printf( "\r\nSTM32H743 Running @ %lu MHz", clk_mhz );

  printf( "\r\nBluetail Technologies OS starting..." );


  int ii;

  int16_t *sptr;
  int ii_len;

  int free = _mem_free();
  printf( "\r\nheap mem free %d bytes\r\n", free );

  MX_GPIO_Init();
  MX_USART6_UART_Init();
  lcd_init();

  HAL_Delay( 1000 );  //increase this from 100 to 1000 in order to get USB communications working on some devices

#if 1
  //HAL_PWREx_EnableUSBReg();
  HAL_PWREx_EnableUSBVoltageDetector();
#else
  HAL_PWREx_DisableUSBVoltageDetector();
  HAL_PWREx_DisableUSBReg();
#endif
  HAL_Delay( 100 );

  printf( "\r\nUSB Init" );
  /* Init Host Library */
  USBH_Init( &hUSBHost, USBH_UserProcess, 0 );

  printf( "\r\nUSB Reg CDC" );
  /* Add Supported Class */
  USBH_RegisterClass( &hUSBHost, USBH_CDC_CLASS );


  /* Start Host Process */
  USBH_Start( &hUSBHost );

  printf( "\r\nUSB Start" );

  GetDefaultConfiguration();
  //USBH_ReEnumerate(&hUSBHost);
  //USBH_CDC_Stop(&hUSBHost);


  MX_DMA_Init();
  MX_I2S2_Init();
  update_i2s_clock();
  HAL_I2S_Transmit_DMA( &hi2s2, audio_tx, AUDIO_DMASIZE );

  //audio_started=1;
  //HAL_GPIO_WritePin( AUDIO_EN_PORT, AUDIO_EN, GPIO_PIN_SET );


  printf( "\r\nStarting Main Loop" );

  while( 1 ) {

    USBH_Process( &hUSBHost );

    lcd_tick();

    if(do_usb_start) {
      uint32_t prim = __get_PRIMASK();
      __disable_irq();
        do_usb_start=0;
        usb_start_rx();
      if( !prim ) {
        __enable_irq();
      }
    }

  }

}

/////////////////////////////////////////////
// delay for 3 clock cycles * ulCount
/////////////////////////////////////////////
void __attribute__( ( naked ) ) DelayClk3( unsigned long ulCount )
{
  __asm( "    subs    r0, #1\n"
         "    bne     DelayClk3\n"
         "    bx      lr" );
}
/////////////////////////////////////////////
/////////////////////////////////////////////
void delay_ms_ni( int delay )
{
  delay_us_ni( 1500 * delay );
}
/////////////////////////////////////////////
/////////////////////////////////////////////
void delay_ms( int delay )
{
  HAL_Delay( delay );
}
/////////////////////////////////////////////
/////////////////////////////////////////////
void delay_us_ni( int delay )
{
  DelayClk3( delay * 134 );
}
/////////////////////////////////////////////
/////////////////////////////////////////////
void delay_us( int delay )
{
  DelayClk3( delay * 134 );
  //delay_us_ni( delay );
  //DelayClk3( delay );
}


/////////////////////////////////////////////////////////////////////////////////////////////////////////
/////////////////////////////////////////////////////////////////////////////////////////////////////////
void lcd_tick()
{
  uint32_t prim;

  current_time = HAL_GetTick();

  if( ( current_time - lcd_tick_time ) > 50 || pen_down ) {
    lcd_tick_time = current_time;

    lcd_test_tick();

  }

  if( current_time - ms_tick_time > 0 ) {

    #if 0
  uint32_t prim = __get_PRIMASK();
  __disable_irq();
    usb_restart_count++;
    if(usb_restart_count>8000) {
      usb_restart_count=0;
      usb_restart();
    }
  if( !prim ) {
    __enable_irq();
  }
    #else
      usb_restart_count++;
      if(usb_restart_count>6000 && lcd_is_usb_connected && do_usb_start==0) {
        usb_restart_count=0;

        usb_restart();

        uint32_t prim = __get_PRIMASK();
        __disable_irq();
          do_usb_start=1;
        if( !prim ) {
          __enable_irq();
        }

      }
    #endif

    ms_tick_time = current_time;
    lcd_tick_ms();

    if( is_playing ) {
      silent_cnt = 0;
    } else {
      //turn off speaker/headphone power
      if( silent_cnt++ > 180000 ) { //180 seconds
        HAL_GPIO_WritePin( AUDIO_EN_PORT, AUDIO_EN, GPIO_PIN_RESET );
      }
    }


    prim = __get_PRIMASK();
    __disable_irq();
      start_rx_cnt++;
    if( !prim ) {
      __enable_irq();
    }
    if( start_rx_cnt % 1000 ==0) {
      usb_tick();
    }

  }


#if 0
  if( ++start_rx_cnt == 6000 ) {
    HAL_GPIO_WritePin( USB_EN_PORT, USB_EN, GPIO_PIN_RESET );
    printf( "\r\nUSB VBUS off" );
    HAL_Delay( 100 );
    HAL_GPIO_WritePin( USB_EN_PORT, USB_EN, GPIO_PIN_SET );
    printf( "\r\nUSB VBUS on" );
  }
#endif



}

/////////////////////////////////////////////////////////////////////////////////////////////
//_Error_Handler( __FILE__, __LINE__ );
/////////////////////////////////////////////////////////////////////////////////////////////
void SystemClock_Config( void )
{
  RCC_OscInitTypeDef RCC_OscInitStruct = {0};
  RCC_ClkInitTypeDef RCC_ClkInitStruct = {0};
  RCC_PeriphCLKInitTypeDef PeriphClkInitStruct = {0};

  /** Supply configuration update enable
  */
  HAL_PWREx_ConfigSupply( PWR_LDO_SUPPLY );
  /** Configure the main internal regulator output voltage
  */
  __HAL_PWR_VOLTAGESCALING_CONFIG( PWR_REGULATOR_VOLTAGE_SCALE0 );

  while( !__HAL_PWR_GET_FLAG( PWR_FLAG_VOSRDY ) ) {}
  /** Macro to configure the PLL clock source
  */
  __HAL_RCC_PLL_PLLSOURCE_CONFIG( RCC_PLLSOURCE_HSE );
  /** Initializes the CPU, AHB and APB busses clocks
  */
  RCC_OscInitStruct.OscillatorType = RCC_OSCILLATORTYPE_HSE;
  RCC_OscInitStruct.HSEState = RCC_HSE_ON;
  RCC_OscInitStruct.PLL.PLLState = RCC_PLL_ON;
  RCC_OscInitStruct.PLL.PLLSource = RCC_PLLSOURCE_HSE;
  RCC_OscInitStruct.PLL.PLLM = 1;

  RCC_OscInitStruct.PLL.PLLN = 120; //480 MHz with 8MHz ref.  USB 48 MHz clock depends on this

  RCC_OscInitStruct.PLL.PLLP = 2;
  RCC_OscInitStruct.PLL.PLLQ = 20;
  RCC_OscInitStruct.PLL.PLLR = 2;
  RCC_OscInitStruct.PLL.PLLRGE = RCC_PLL1VCIRANGE_3;
  RCC_OscInitStruct.PLL.PLLVCOSEL = RCC_PLL1VCOWIDE;
  RCC_OscInitStruct.PLL.PLLFRACN = 0;
  if( HAL_RCC_OscConfig( &RCC_OscInitStruct ) != HAL_OK ) {
    _Error_Handler( __FILE__, __LINE__ );
  }
  /** Initializes the CPU, AHB and APB busses clocks
  */
  RCC_ClkInitStruct.ClockType = RCC_CLOCKTYPE_HCLK | RCC_CLOCKTYPE_SYSCLK
                                | RCC_CLOCKTYPE_PCLK1 | RCC_CLOCKTYPE_PCLK2
                                | RCC_CLOCKTYPE_D3PCLK1 | RCC_CLOCKTYPE_D1PCLK1;
  RCC_ClkInitStruct.SYSCLKSource = RCC_SYSCLKSOURCE_PLLCLK;
  RCC_ClkInitStruct.SYSCLKDivider = RCC_SYSCLK_DIV1;
  RCC_ClkInitStruct.AHBCLKDivider = RCC_HCLK_DIV2;
  RCC_ClkInitStruct.APB3CLKDivider = RCC_APB3_DIV2;
  RCC_ClkInitStruct.APB1CLKDivider = RCC_APB1_DIV2;
  RCC_ClkInitStruct.APB2CLKDivider = RCC_APB2_DIV2;
  RCC_ClkInitStruct.APB4CLKDivider = RCC_APB4_DIV2;

  if( HAL_RCC_ClockConfig( &RCC_ClkInitStruct, FLASH_LATENCY_4 ) != HAL_OK ) {
    _Error_Handler( __FILE__, __LINE__ );
  }
  PeriphClkInitStruct.PeriphClockSelection = RCC_PERIPHCLK_SPI3 | RCC_PERIPHCLK_SPI2
      | RCC_PERIPHCLK_ADC | RCC_PERIPHCLK_USB;
  PeriphClkInitStruct.PLL2.PLL2M = 1;
  PeriphClkInitStruct.PLL2.PLL2N = 18;
  PeriphClkInitStruct.PLL2.PLL2P = 1;
  PeriphClkInitStruct.PLL2.PLL2Q = 2;
  PeriphClkInitStruct.PLL2.PLL2R = 2;
  PeriphClkInitStruct.PLL2.PLL2RGE = RCC_PLL2VCIRANGE_3;
  PeriphClkInitStruct.PLL2.PLL2VCOSEL = RCC_PLL2VCOMEDIUM;
  PeriphClkInitStruct.PLL2.PLL2FRACN = 6144;
  PeriphClkInitStruct.PLL3.PLL3M = 1;
  PeriphClkInitStruct.PLL3.PLL3N = 18;
  PeriphClkInitStruct.PLL3.PLL3P = 2;
  PeriphClkInitStruct.PLL3.PLL3Q = 2;
  PeriphClkInitStruct.PLL3.PLL3R = 1;
  PeriphClkInitStruct.PLL3.PLL3RGE = RCC_PLL3VCIRANGE_3;
  PeriphClkInitStruct.PLL3.PLL3VCOSEL = RCC_PLL3VCOMEDIUM;
  PeriphClkInitStruct.PLL3.PLL3FRACN = 6144;
  PeriphClkInitStruct.Spi123ClockSelection = RCC_SPI123CLKSOURCE_PLL2;
  PeriphClkInitStruct.UsbClockSelection = RCC_USBCLKSOURCE_PLL;
  PeriphClkInitStruct.AdcClockSelection = RCC_ADCCLKSOURCE_PLL3;
  if( HAL_RCCEx_PeriphCLKConfig( &PeriphClkInitStruct ) != HAL_OK ) {
    _Error_Handler( __FILE__, __LINE__ );
  }
  /** Enable USB Voltage detector
  */
  HAL_PWREx_EnableUSBVoltageDetector();
}

//////////////////////////////////////////////////////////////
//////////////////////////////////////////////////////////////
static void MX_USART6_UART_Init( void )
{

  huart6.Instance = USART6;
  huart6.Init.BaudRate = 2000000;
  huart6.Init.WordLength = UART_WORDLENGTH_8B;
  huart6.Init.StopBits = UART_STOPBITS_1;
  huart6.Init.Parity = UART_PARITY_NONE;
  huart6.Init.Mode = UART_MODE_TX_RX;
  huart6.Init.HwFlowCtl = UART_HWCONTROL_NONE;
  huart6.Init.OverSampling = UART_OVERSAMPLING_16;
  huart6.Init.OneBitSampling = UART_ONE_BIT_SAMPLE_DISABLE;
  //huart6.Init.Prescaler = UART_PRESCALER_DIV1;
  //huart6.Init.FIFOMode = UART_FIFOMODE_DISABLE;
  //huart6.Init.TXFIFOThreshold = UART_TXFIFO_THRESHOLD_1_8;
  //huart6.Init.RXFIFOThreshold = UART_RXFIFO_THRESHOLD_1_8;
  huart6.AdvancedInit.AdvFeatureInit = UART_ADVFEATURE_NO_INIT;
  if( HAL_UART_Init( &huart6 ) != HAL_OK ) {
    _Error_Handler( __FILE__, __LINE__ );
  }

}

//////////////////////////////////////////////////////////////
//////////////////////////////////////////////////////////////
static void MX_GPIO_Init( void )
{


  GPIO_InitTypeDef GPIO_InitStruct;

  /* GPIO Ports Clock Enable */
  __HAL_RCC_GPIOC_CLK_ENABLE();
  __HAL_RCC_GPIOH_CLK_ENABLE();
  __HAL_RCC_GPIOA_CLK_ENABLE();
  __HAL_RCC_GPIOB_CLK_ENABLE();
  __HAL_RCC_GPIOD_CLK_ENABLE();
  __HAL_RCC_GPIOE_CLK_ENABLE();
  __HAL_RCC_GPIOG_CLK_ENABLE();


//LCD PORT A
//#define LCD_T_CS_PORT GPIOA
//#define LCD_T_CS GPIO_PIN_3
//#define LCD_CS_PORT GPIOA
//#define LCD_CS GPIO_PIN_4
//#define LCD_SCK_PORT GPIOA
//#define LCD_SCK GPIO_PIN_5
//#define LCD_MISO_PORT GPIOA
//#define LCD_MISO GPIO_PIN_6
//#define LCD_MOSI_PORT GPIOA
//#define LCD_MOSI GPIO_PIN_7

//LCD PORT E
//#define LCD_RESET_PORT GPIOE
//#define LCD_RESET GPIO_PIN_7
//#define LCD_DC_PORT GPIOE
//#define LCD_DC GPIO_PIN_8
//#define LCD_LED_PORT GPIOE
//#define LCD_LED GPIO_PIN_9
//#define LCD_T_CLK_PORT GPIOE
//#define LCD_T_CLK GPIO_PIN_10
//#define LCD_T_DOUT_PORT GPIOE
//#define LCD_T_DOUT GPIO_PIN_11
//#define LCD_T_DIN_PORT GPIOE
//#define LCD_T_DIN GPIO_PIN_12
//#define LCD_T_IRQ_PORT GPIOE
//#define LCD_T_IRQ GPIO_PIN_13


  //PORT A   LCD PINS
  GPIO_InitStruct.Pin = GPIO_PIN_3 | GPIO_PIN_4 | GPIO_PIN_5 | GPIO_PIN_7 | GPIO_PIN_1 | GPIO_PIN_2 ;
  GPIO_InitStruct.Mode = GPIO_MODE_OUTPUT_PP;
  GPIO_InitStruct.Pull = GPIO_NOPULL;
  GPIO_InitStruct.Speed = GPIO_SPEED_FREQ_HIGH;
  HAL_GPIO_Init( GPIOA, &GPIO_InitStruct );

  //PORT E   LCD PINS
  GPIO_InitStruct.Pin = GPIO_PIN_7 | GPIO_PIN_8 | GPIO_PIN_9 | GPIO_PIN_10 | GPIO_PIN_12;
  GPIO_InitStruct.Mode = GPIO_MODE_OUTPUT_PP;
  GPIO_InitStruct.Pull = GPIO_NOPULL;
  GPIO_InitStruct.Speed = GPIO_SPEED_FREQ_HIGH;
  HAL_GPIO_Init( GPIOE, &GPIO_InitStruct );

  //lcd inputs GPIOE
  GPIO_InitStruct.Pin = GPIO_PIN_11 | GPIO_PIN_13;
  GPIO_InitStruct.Mode = GPIO_MODE_INPUT;
  GPIO_InitStruct.Pull = GPIO_PULLUP;
  GPIO_InitStruct.Speed = GPIO_SPEED_FREQ_HIGH;
  HAL_GPIO_Init( GPIOE, &GPIO_InitStruct );

  //lcd inputs GPIOA
  GPIO_InitStruct.Pin = GPIO_PIN_6 ; //lcd miso
  GPIO_InitStruct.Mode = GPIO_MODE_INPUT;
  GPIO_InitStruct.Pull = GPIO_PULLUP;
  GPIO_InitStruct.Speed = GPIO_SPEED_FREQ_HIGH;
  HAL_GPIO_Init( GPIOA, &GPIO_InitStruct );

  HAL_GPIO_WritePin( LCD_SCK_PORT, LCD_SCK, GPIO_PIN_RESET );//lcd SCK
  HAL_GPIO_WritePin( LCD_CS_PORT, LCD_CS, GPIO_PIN_SET );//lcd cs
  HAL_GPIO_WritePin( LCD_RESET_PORT, LCD_RESET, GPIO_PIN_RESET ); //lcd reset
  HAL_GPIO_WritePin( LCD_LED_PORT, LCD_LED, GPIO_PIN_SET );//lcd led
  HAL_GPIO_WritePin( LCD_T_CS_PORT, LCD_T_CS, GPIO_PIN_SET );

  HAL_GPIO_WritePin( FLASH_CS_PORT, FLASH_CS, GPIO_PIN_SET );
  HAL_GPIO_WritePin( SD_CS_PORT, SD_CS, GPIO_PIN_SET );


  //USB power  PD5
  HAL_GPIO_WritePin( USB_EN_PORT, USB_EN, GPIO_PIN_SET );//ON
  GPIO_InitStruct.Pin = USB_EN;
  GPIO_InitStruct.Mode = GPIO_MODE_OUTPUT_PP;
  GPIO_InitStruct.Pull = GPIO_NOPULL;
  GPIO_InitStruct.Speed = GPIO_SPEED_FREQ_HIGH;
  HAL_GPIO_Init( USB_EN_PORT, &GPIO_InitStruct );

  //AUDIO amp enable
  HAL_GPIO_WritePin( AUDIO_EN_PORT, AUDIO_EN, GPIO_PIN_RESET );
  GPIO_InitStruct.Pin = AUDIO_EN;
  GPIO_InitStruct.Mode = GPIO_MODE_OUTPUT_PP;
  GPIO_InitStruct.Pull = GPIO_NOPULL;
  GPIO_InitStruct.Speed = GPIO_SPEED_FREQ_HIGH;
  HAL_GPIO_Init( AUDIO_EN_PORT, &GPIO_InitStruct );

}


//////////////////////////////////////////////////////////////
//////////////////////////////////////////////////////////////
static void MPU_Config( void )
{
  MPU_Region_InitTypeDef MPU_InitStruct;

  /* Disable the MPU */
  HAL_MPU_Disable();

  MPU_InitStruct.Enable = MPU_REGION_ENABLE;
  MPU_InitStruct.BaseAddress = audio_tx;
  MPU_InitStruct.Size = MPU_REGION_SIZE_1KB;
  MPU_InitStruct.AccessPermission = MPU_REGION_FULL_ACCESS;
  MPU_InitStruct.IsBufferable = MPU_ACCESS_BUFFERABLE;
  MPU_InitStruct.IsCacheable = MPU_ACCESS_NOT_CACHEABLE;
  MPU_InitStruct.IsShareable = MPU_ACCESS_SHAREABLE;
  MPU_InitStruct.Number = MPU_REGION_NUMBER4;
  MPU_InitStruct.TypeExtField = MPU_TEX_LEVEL0;
  MPU_InitStruct.SubRegionDisable = 0x00;
  MPU_InitStruct.DisableExec = MPU_INSTRUCTION_ACCESS_ENABLE;

  HAL_MPU_ConfigRegion( &MPU_InitStruct );


  /* Enable the MPU */
  HAL_MPU_Enable( MPU_PRIVILEGED_DEFAULT );
}

//////////////////////////////////////////////////////////////
//////////////////////////////////////////////////////////////
void _Error_Handler( char *file, int line )
{
  while( 1 ) {
  }
}

//////////////////////////////////////////////////////////////
//////////////////////////////////////////////////////////////
#ifdef  USE_FULL_ASSERT
void assert_failed( uint8_t *file, uint32_t line )
{
}
#endif /* USE_FULL_ASSERT */
////////////////////////////////////////////////////////////////////////
////////////////////////////////////////////////////////////////////////
void MX_I2S2_Init( void )
{

  hi2s2.Instance = SPI2;
  hi2s2.Init.Mode = I2S_MODE_MASTER_TX;
  hi2s2.Init.Standard = I2S_STANDARD_PHILIPS;
  hi2s2.Init.DataFormat = I2S_DATAFORMAT_16B;
  hi2s2.Init.MCLKOutput = I2S_MCLKOUTPUT_ENABLE;
  //hi2s2.Init.AudioFreq = I2S_AUDIOFREQ_16K;
  //hi2s2.Init.AudioFreq = I2S_AUDIOFREQ_48K;
  hi2s2.Init.AudioFreq = I2S_AUDIOFREQ_8K;
  hi2s2.Init.CPOL = I2S_CPOL_LOW;
  hi2s2.Init.FirstBit = I2S_FIRSTBIT_MSB;
  hi2s2.Init.WSInversion = I2S_WS_INVERSION_DISABLE;
  hi2s2.Init.Data24BitAlignment = I2S_DATA_24BIT_ALIGNMENT_RIGHT;
  hi2s2.Init.MasterKeepIOState = I2S_MASTER_KEEP_IO_STATE_ENABLE;
  if( HAL_I2S_Init( &hi2s2 ) != HAL_OK ) {
    _Error_Handler( __FILE__, __LINE__ );
  }

}

//////////////////////////////////////////////////////////////////////////
//////////////////////////////////////////////////////////////////////////
void HAL_I2S_TxHalfCpltCallback( I2S_HandleTypeDef *hi2s )
{
  handle_i2s_double_buffer( &audio_tx[0] );
}
//////////////////////////////////////////////////////////////////////////
//////////////////////////////////////////////////////////////////////////
void HAL_I2S_TxCpltCallback( I2S_HandleTypeDef *hi2s )
{
  handle_i2s_double_buffer( &audio_tx[AUDIO_DMASIZE / 2] );
}

//////////////////////////////////////////////////////////////////////////
//////////////////////////////////////////////////////////////////////////
void handle_i2s_double_buffer( int16_t *audio_tx_ptr )
{

  int vi;
  int i;

  int do_stop = 0;

  if( audio_started == 0 ) {
    is_playing = 0;
    uint8_t *ptr = ( uint8_t * ) audio_tx;

    for( i = 0; i < AUDIO_DMASIZE / 4; i++ ) {
      *audio_tx_ptr++ = ( uint16_t ) 0;
      *audio_tx_ptr++ = ( uint16_t ) 0;
    }
    return;
  }


  for( vi = 0; vi < AUDIO_DMASIZE / 4; vi++ ) {

    if( ( is_playing && out_s != out_e ) ) {

      if(!mute_audio) {
        *audio_tx_ptr++ = ( int16_t )( out_buffer[out_s] *  volume );
        *audio_tx_ptr++ = ( int16_t )( out_buffer[out_s++] *  volume );
      }
      else {
        out_s++;
        *audio_tx_ptr++ = 0; 
        *audio_tx_ptr++ = 0; 
      }
      out_s &= AUDIO_OUT_BUFFER_SIZE - 1;

    } else {
      do_stop = 1;

      *audio_tx_ptr++ = 0;   //silence
      *audio_tx_ptr++ = 0;
    }
  }


  if( do_stop ) {
    is_playing = 0;
    do_stop = 0;
  }

}
//////////////////////////////////////////////////////////////////////
//////////////////////////////////////////////////////////////////////
void update_i2s_clock()
{
  RCC_PeriphCLKInitTypeDef PeriphClkInitStruct = {0};

  PeriphClkInitStruct.PeriphClockSelection = RCC_PERIPHCLK_SPI3 | RCC_PERIPHCLK_SPI2
      | RCC_PERIPHCLK_ADC;
  PeriphClkInitStruct.PLL2.PLL2M = 1;     //PLL2 clocks the audio I2S,
  //PeriphClkInitStruct.PLL2.PLL2N = 122;   //audio playback rate for 8kHz
  PeriphClkInitStruct.PLL2.PLL2N = 118;   //slower playback
  PeriphClkInitStruct.PLL2.PLL2P = 4;
  PeriphClkInitStruct.PLL2.PLL2Q = 4;
  PeriphClkInitStruct.PLL2.PLL2R = 4;
  PeriphClkInitStruct.PLL2.PLL2RGE = RCC_PLL2VCIRANGE_2;
  PeriphClkInitStruct.PLL2.PLL2VCOSEL = RCC_PLL2VCOWIDE;
  PeriphClkInitStruct.PLL2.PLL2FRACN = 1;

  PeriphClkInitStruct.PLL3.PLL3M = 1;
  PeriphClkInitStruct.PLL3.PLL3N = 23;
  PeriphClkInitStruct.PLL3.PLL3P = 8;
  PeriphClkInitStruct.PLL3.PLL3Q = 2;
  PeriphClkInitStruct.PLL3.PLL3R = 2;
  PeriphClkInitStruct.PLL3.PLL3RGE = RCC_PLL3VCIRANGE_3;
  PeriphClkInitStruct.PLL3.PLL3VCOSEL = RCC_PLL3VCOMEDIUM;
  PeriphClkInitStruct.PLL3.PLL3FRACN = 7987;
  PeriphClkInitStruct.Spi123ClockSelection = RCC_SPI123CLKSOURCE_PLL2;
  PeriphClkInitStruct.AdcClockSelection = RCC_ADCCLKSOURCE_PLL3;

  if( HAL_RCCEx_PeriphCLKConfig( &PeriphClkInitStruct ) != HAL_OK ) {
    _Error_Handler( __FILE__, __LINE__ );
  }


}
//////////////////////////////////////////////////////////////////////////
//////////////////////////////////////////////////////////////////////////
static void MX_DMA_Init( void )
{
  /* DMA controller clock enable */
  __HAL_RCC_DMA1_CLK_ENABLE();
  __HAL_RCC_DMA2_CLK_ENABLE();

  HAL_NVIC_SetPriority( DMA1_Stream1_IRQn, 0, 0 );
  HAL_NVIC_EnableIRQ( DMA1_Stream1_IRQn );

}

//////////////////////////////////////////////////////////////////////////////////
// audio agc
//////////////////////////////////////////////////////////////////////////////////
float update_gain_s16( int16_t *audio, int len, float target, float rate )
{
  int i;

  for( i = 0; i < len; i++ ) {
    tmp_buffer_f[i] = ( float ) audio[i];
  }

  update_gain_f32(tmp_buffer_f, len, target, rate);

  for( i = 0; i < len; i++ ) {
    audio[i] = ( int16_t ) tmp_buffer_f[i];
  }

}
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

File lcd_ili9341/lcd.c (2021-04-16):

//MIT License
//
//Copyright (c) 2020 tvelliott
//
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
#include "stm32h7xx_hal.h"
#include "lcd.h"
#include "fonts.h"
#include <stdlib.h>
#include "main.h" 

const uint8_t display_init[] = {
  0xEF, 3, 0x03, 0x80, 0x02,
  0xCF, 3, 0x00, 0xC1, 0x30,
  0xED, 4, 0x64, 0x03, 0x12, 0x81,
  0xE8, 3, 0x85, 0x00, 0x78,
  0xCB, 5, 0x39, 0x2C, 0x00, 0x34, 0x02,
  0xF7, 1, 0x20,
  0xEA, 2, 0x00, 0x00,
  ILI9341_PWCTR1, 1, 0x23,
  ILI9341_PWCTR2, 1, 0x10,
  ILI9341_VMCTR1, 2, 0x3e, 0x28,
  ILI9341_VMCTR2, 1, 0x86,
  ILI9341_MADCTL, 1, 0x48,
  ILI9341_VSCRSADD, 1, 0x00,
  ILI9341_PIXFMT, 1, 0x55,
  ILI9341_FRMCTR1, 2, 0x00, 0x18,
  ILI9341_DFUNCTR, 3, 0x08, 0x82, 0x27,
  0xF2, 1, 0x00,
  ILI9341_GAMMASET, 1, 0x01,
  ILI9341_GMCTRP1, 15, 0x0F, 0x31, 0x2B, 0x0C, 0x0E, 0x08,
  0x4E, 0xF1, 0x37, 0x07, 0x10, 0x03, 0x0E, 0x09, 0x00,
  ILI9341_GMCTRN1, 15, 0x00, 0x0E, 0x14, 0x03, 0x11, 0x07,
  0x31, 0xC1, 0x48, 0x08, 0x0F, 0x0C, 0x31, 0x36, 0x0F,
  ILI9341_SLPOUT, 0x80,
  ILI9341_DISPON, 0x80,
  0x00
};

uint16_t lcd_width;
uint16_t lcd_height;
uint16_t lcd_rotation;
int delay_val = 5;

uint8_t pen_down;

const int pen_w = 4;
uint8_t draw_txt[128];
uint16_t line_data[240];

uint16_t prev_x;
uint16_t prev_y;
uint32_t npoints;

uint16_t scroll_val = 130 + 60;
static int did_init;

int lcd_is_usb_connected;
int volatile update_usb_connect;
volatile int usb_rx_count;

//////////////////////////////////////////////////////////////////////////
//////////////////////////////////////////////////////////////////////////
void lcd_init()
{

  uint8_t cmd, x, numArgs;
  const uint8_t *ptr = display_init;

  delay_ms_ni( 5 );
  HAL_GPIO_WritePin( LCD_RESET_PORT, LCD_RESET, GPIO_PIN_RESET ); //lcd reset
  delay_ms_ni( 50 );
  HAL_GPIO_WritePin( LCD_RESET_PORT, LCD_RESET, GPIO_PIN_SET ); //lcd reset
  delay_ms_ni( 50 );

  while( 1 ) {
    cmd = *ptr++;  //command
    if( cmd == 0 ) break;

    //if(cmd==0xff) cmd=0; //NOP

    x = *ptr++;    //n args

    numArgs = ( x & 0x7f );
    lcd_send_command( cmd, ptr, numArgs );

    ptr += numArgs;
    if( x & 0x80 ) {
      delay_ms_ni( 150 );
    }
  }

  lcd_width = ILI9341_TFTWIDTH;
  lcd_height = ILI9341_TFTHEIGHT;
  HAL_GPIO_WritePin( LCD_CS_PORT, LCD_CS, GPIO_PIN_SET );//lcd CS high


  lcd_set_draw_port( 0, 0, lcd_width, lcd_height );
  lcd_fill( ILI9341_BLACK );
  lcd_set_rotation( 2 );

  lcd_set_scroll_def( 130, 60, 130 ); //should add up to 320
  scroll_val = 130;


  //touch display related
  HAL_GPIO_WritePin( LCD_T_CLK_PORT, LCD_T_CLK, GPIO_PIN_RESET );
  HAL_GPIO_WritePin( LCD_T_CS_PORT, LCD_T_CS, GPIO_PIN_RESET );
  HAL_GPIO_WritePin( LCD_LED_PORT, LCD_LED, GPIO_PIN_SET );//lcd led

  lcd_page1_init();
  lcd_page2_init();
  lcd_page3_init();
  lcd_page4_init();
  lcd_page5_init();

}

///////////////////////////////////////////////////////////////////////
///////////////////////////////////////////////////////////////////////
void lcd_set_rotation( uint8_t rot )
{

  lcd_rotation = ( rot & 0x03 );

  uint8_t m;

  switch( ( int ) lcd_rotation ) {
  case 0:
    m = ( MADCTL_MX | MADCTL_BGR );
    lcd_width = ILI9341_TFTWIDTH;
    lcd_height = ILI9341_TFTHEIGHT;
    break;
  case 1:
    m = ( MADCTL_MV | MADCTL_BGR );
    lcd_width = ILI9341_TFTHEIGHT;
    lcd_height = ILI9341_TFTWIDTH;
    break;
  case 2:
    m = ( MADCTL_MY | MADCTL_BGR );
    lcd_width = ILI9341_TFTWIDTH;
    lcd_height = ILI9341_TFTHEIGHT;
    break;
  case 3:
    m = ( MADCTL_MX | MADCTL_MY | MADCTL_MV | MADCTL_BGR );
    lcd_width = ILI9341_TFTHEIGHT;
    lcd_height = ILI9341_TFTWIDTH;
    break;
  }

  lcd_send_command( ILI9341_MADCTL, &m, 1 );
  HAL_GPIO_WritePin( LCD_CS_PORT, LCD_CS, GPIO_PIN_SET );//lcd CS high
}

/////////////////////////////////////////////////////////////////////////////
/////////////////////////////////////////////////////////////////////////////
void lcd_scroll_to( uint16_t y )
{

  uint8_t data[2];
  data[0] = ( uint8_t )( y >> 8 );
  data[1] = ( uint8_t )( y & 0xff );
  lcd_send_command( ILI9341_VSCRSADD, ( uint8_t * )data, 2 );
  HAL_GPIO_WritePin( LCD_CS_PORT, LCD_CS, GPIO_PIN_SET );//lcd CS high
}

/////////////////////////////////////////////////////////////////////////////
/////////////////////////////////////////////////////////////////////////////
void lcd_set_scroll_def( uint16_t top, uint16_t sa, uint16_t bottom )
{

  //if( top + bottom <= ILI9341_TFTHEIGHT ) {
  uint8_t data[6];
  data[0] = ( uint8_t )( top >> 8 );
  data[1] = ( uint8_t )( top & 0xff );
  data[2] = ( uint8_t )( sa >> 8 );
  data[3] = ( uint8_t )( sa & 0xff );
  data[4] = ( uint8_t )( bottom >> 8 );
  data[5] = ( uint8_t )( bottom & 0xff );
  lcd_send_command( ILI9341_VSCRDEF, ( uint8_t * )data, 6 );
  //}
  HAL_GPIO_WritePin( LCD_CS_PORT, LCD_CS, GPIO_PIN_SET );//lcd CS high
}

/////////////////////////////////////////////////////////////////////////////////////
/////////////////////////////////////////////////////////////////////////////////////
void lcd_set_draw_port( uint16_t x1, uint16_t y1, uint16_t w, uint16_t h )
{

  lcd_write_command( ILI9341_CASET ); // Column address set
  lcd_spi_write8( x1 >> 8 );
  lcd_spi_write8( x1 & 0xff );
  w = x1 + w - 1;
  lcd_spi_write8( w >> 8 );
  lcd_spi_write8( w & 0xff );

  lcd_cs_high();
  lcd_write_command( ILI9341_PASET ); // Row address set
  lcd_spi_write8( y1 >> 8 );
  lcd_spi_write8( y1 & 0xff );
  h = y1 + h - 1;
  lcd_spi_write8( h >> 8 );
  lcd_spi_write8( h & 0xff );

  HAL_GPIO_WritePin( LCD_CS_PORT, LCD_CS, GPIO_PIN_SET );//lcd CS high
  //lcd_write_command(ILI9341_RAMWR); // Write to RAM
  //lcd_cs_high();
}

///////////////////////////////////////////////////
///////////////////////////////////////////////////
void lcd_fill_rand_rect()
{

  uint16_t yy = rand() % lcd_height;
  uint16_t xx = rand() % lcd_width;
  uint16_t ww = ( rand() % ( lcd_height - yy ) );
  uint16_t hh = ( rand() % ( lcd_width - xx ) );

  lcd_set_draw_port( xx, yy, ww, hh );

  lcd_write_command( ILI9341_RAMWR );
  int i;
  uint8_t col = rand() % 255;
  for( i = 0; i < ( ww * hh * 2 ); i++ ) {

    if( col % 16 == 0 ) {
      lcd_spi_write8( rand() % 255 );
    } else {
      lcd_spi_write8( col );
    }
  }
  lcd_cs_high();

}
///////////////////////////////////////////////////////////////////
///////////////////////////////////////////////////////////////////
void lcd_draw_rect( int x, int y, int w, int h, uint16_t color )
{
  lcd_drawline( color, x, y, x + w, y );
  lcd_drawline( color, x + w, y, x + w, y + h );
  lcd_drawline( color, x + w, y + h, x, y + h );
  lcd_drawline( color, x, y + h, x, y );
}
///////////////////////////////////////////////////////////////////
///////////////////////////////////////////////////////////////////
void lcd_draw_rect_hl( int x, int y, int w, int h )
{
  lcd_drawline( ILI9341_WHITE, x, y, x + w, y );
  lcd_drawline( ILI9341_LIGHTGREY, x + w, y, x + w, y + h );
  lcd_drawline( ILI9341_LIGHTGREY, x + w, y + h, x, y + h );
  lcd_drawline( ILI9341_WHITE, x, y + h, x, y );
}
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

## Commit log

2021-02-28 added eagle files
    [p25rx_display_rev3.brd, p25rx_display_rev3.sch]
2021-02-28 add pdf schematic
2021-04-15 fix issues with usb connectivity between display<>p25rx on power-up
    [main.c, main.h, usbh_conf.c]
2021-04-15 2021-04-15_1554 fix issue with talk group hold button
2021-04-21 update notes on schematic regarding D2
    [p25rx_display_rev3.brd, p25rx_display_rev3.sch]
2021-04-29 increase startup delay to get some new displays USB working with all tested P25RX devices
2021-05-02 add openocd programming related information
    [bluetailtech.cfg]

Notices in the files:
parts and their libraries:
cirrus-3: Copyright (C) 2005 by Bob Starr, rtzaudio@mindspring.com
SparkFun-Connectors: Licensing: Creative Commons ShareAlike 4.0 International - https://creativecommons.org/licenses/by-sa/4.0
